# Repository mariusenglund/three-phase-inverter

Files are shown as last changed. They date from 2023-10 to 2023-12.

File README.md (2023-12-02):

# 3-phase DC/AC converter with SV-PWM
This repository holds materials of our bachelor's thesis carried out at the Western Norway University of Applied Sciences (HVL), Department of Computer Science, Electrical Engineering and Mathematical Sciences in the spring of 2023.

The thesis can be found at [HVL Open](https://hdl.handle.net/11250/3105460).

> We hope that this report will serve as a valuable resource for those who are interested in the field, and we encourage further development of the provided resources.

## About the Project
The project was aimed at realizing the design and fabrication of a three-phase DC-to-AC converter utilizing the Space Vector Pulse Width Modulation (SV-PWM) algorithm.

<p align="center">
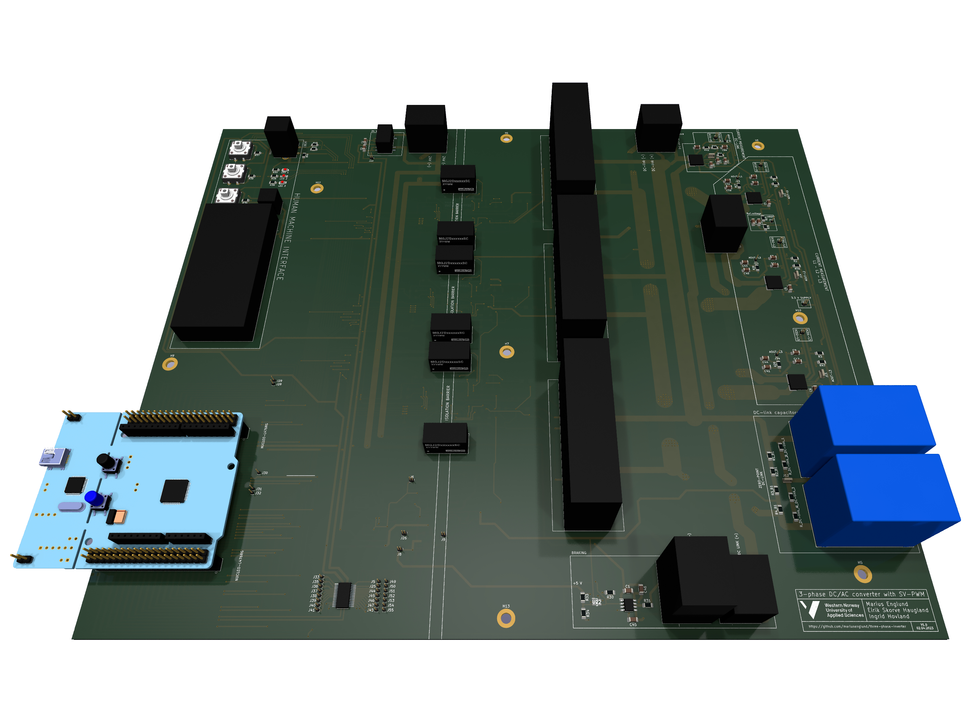
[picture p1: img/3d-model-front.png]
3D Model Front
   
   &nbsp; &nbsp; &nbsp; &nbsp;
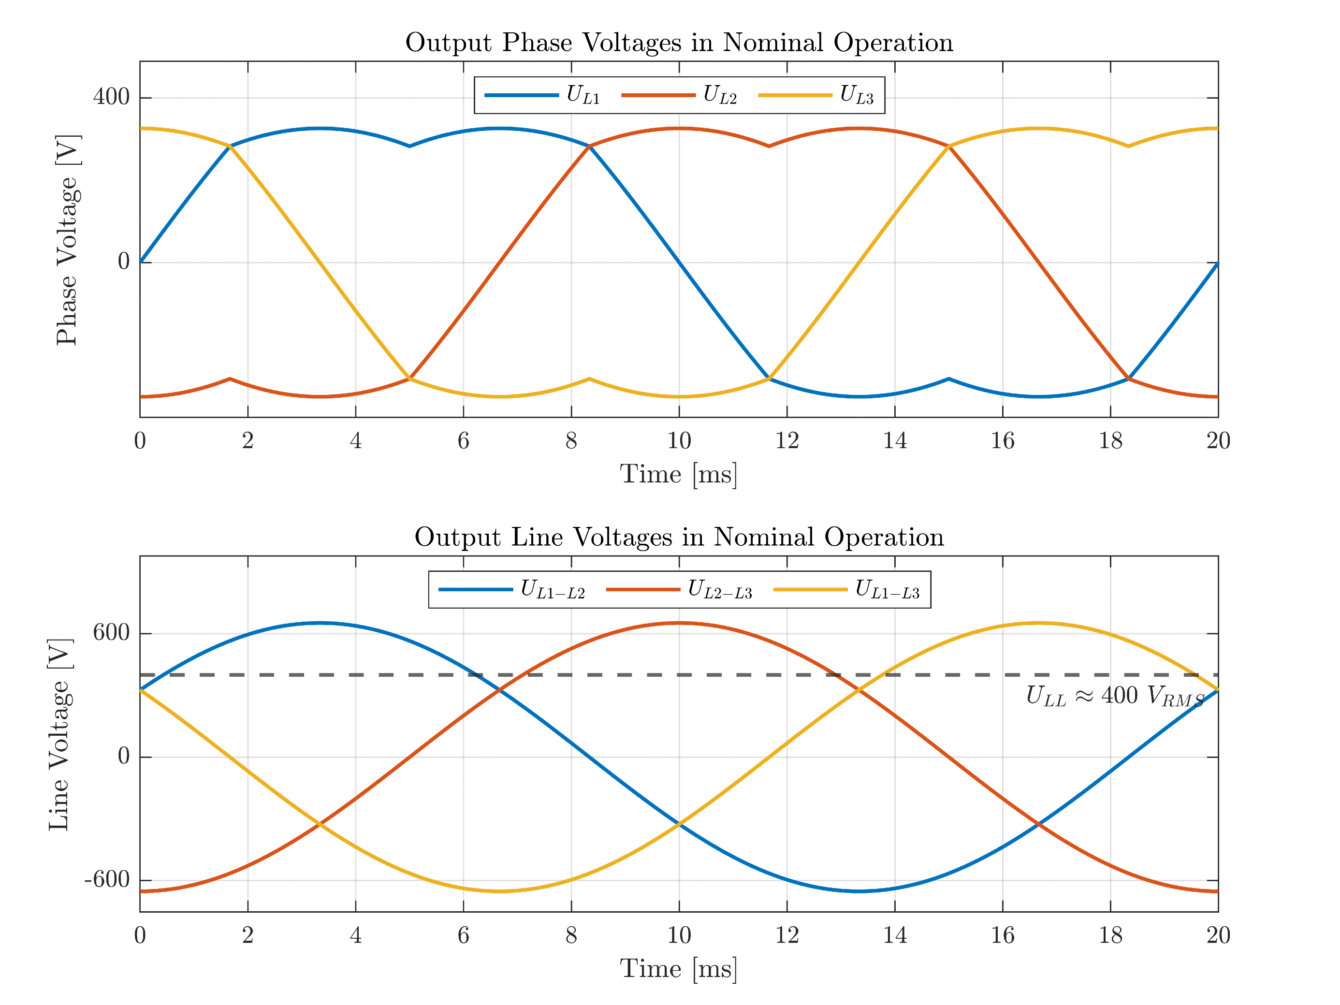
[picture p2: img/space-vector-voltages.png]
Space Vector Voltages
   
</p>

## Further Work
For suggestions on further work, please refer to the thesis.

## Available Resources
In order to facilitate further advancement, the following resources are made accessible from this repo:

* [PCB design files](pcb-design-files)
* [Source code](source-code)
* [Simulation files](simulation-files)

The repository also contains a [laboratory exercise proposal](/laboratory-exercise/laboratory-exercise-proposal.pdf) that makes use of the inverter. It is worth noting that this exercise is presented in Norwegian.

## License
The resources provided in this repository are released under the GNU General Public License. See the [LICENSE](LICENSE) file for more information.

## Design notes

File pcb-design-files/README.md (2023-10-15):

## PCB Design Files
Download the KiCad project from this location.

***Be aware that the files are still a work in progress.***

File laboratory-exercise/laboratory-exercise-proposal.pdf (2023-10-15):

# Lab - 2-nivå trefase DC/AC-omformar¹

## Emnekode: ELE119

## Emnenamn: Kraftelektronikk

## Haust 2023

Labansvarleg: Lars M. Ekroll lme@hvl.no

Emneansvarlig: Eirik Haustveit
| ehau@hvl.no

Utlevert:
dd.mm.åååå

Frist:
dd.mm.åååå
Gjennomføring:
dd.mm.åååå

Denne laboratorieoppgåva dekker grunnleggande praktisk bruk av ein 2-nivå trefase DC/AC-omformar.

Spenningane og straumane som skal nyttast i oppgåva er moderate, men framleis på eit nivå som medfører

fare. Før arbeidet kan starta er det derfor obligatorisk med ein sikkerhetsgjennomgang for alle studentar

som skal gjennomføra oppgåva.

Figur 1: 150 V, livsfare.

- 2-nivå trefase-omformar
- Romvektormodulering - SV-PWM
- Sinuspulsbreiddemodulering - SPWM

1 Denne laboratorieoppgåva er utvikla av Marius Englund, Eirik Skorve Haugland og Ingrid Hovland, med utgangspunkt i ein mal utarbeidd av Eirik Haustveit.

Lab 1 | ELE119 - Kraftelektronikk | Haust 2023

## 1 Introduksjon

Denne laboratorieoppgåva dekker 2-nivå trefase-omformar. Oppgåva er strukturert i 3 delar:

1. Forarbeid: Her skal ein berekne nokre aktuelle parameter. I tillegg skal ein simulera berekna verdiar. Resultata frå berekningar og simuleringar skal noterast i oversiktstabellen.
2. Laboratoriearbeid: Her skal ein utføre oppkoplinga, samt måling på dei fysiske modellane. Det vil være ein stor fordel om ein har gjort seg godt kjent med ein simuleringsmodell og verktøya i forkant. Grunnleggande forståing for dei to modulasjonsteknikkane SPWM og SV-PWM er og ein stor fordel. Ein skal samle måleresultat i all hovudsak ved hjelp av oscilloskop. På oscillioskopet har ein verktøy som er kjent frå Simulink, som å måla verdiar som RMS, snitt, peak-peak, FFT m.m. Ein skal også lagre datasett som CSV-filer for å kunne etterbehandla dei i Matlab. Her er det viktig at ein organiserer arbeidet, slik at ein har kontroll på kva målingar som ligg i eit gitt datasett.
3. Etterarbeid: I etterarbeidet skal ein samanlikne utrekna, simulerte og fysiske måleresultat og studere avvika som ev. viser seg. Ein skal og tolke datasett frå laboratoriearbeidet.

Arbeidet skal oppsummerast i ein enkel rapport som dokumenter dei ulike delane av oppgåva.

### 1.1 Føresetnader

Arbeidet blir utført på spenningssatt anlegg med maksimal spenning 230 V. Då dette er eit spenningsnivå som har skadepotensial for både personar og utstyr, er ein tryggleiksgjennomgang med ansvarleg for elkraft-laboratoriet, Lars M. Ekrol påkrevd før den praktiske delen av oppgåva kan gjennomførast.

### 1.2 Utstyr

Under fylgjer ei liste over utstyr som blir gjort tilgjengeleg for den praktiske gjennomføringa. Noter utstyrsnummeret du har brukt i tabell 1. Om det er avvik frå ditt oppsett skal dette avviket noterast i din rapport.

Tabell 1: Liste over utstyr til lab

Utstyr | Skildring | Utstyrsnr | Kommentar
Trafo | 2 kVA trafo, 220/133 V
Brytar | Brytar i tilførsel
Brytar | Brytar i last
Sikring | 3 fase, 2/6 A
Koblingsboks | For tilkopling og måling
Kraftmodul | 2-nivå trefase-omformar
Spenningsprobe 1 | Micsig DP1003
Spenningsprobe 2 | Micsig DP1003
Strømtang 1 | Micsig CP2100A
Strømtang 2 | Micsig CP2100A
Multimeter | Hioki DT4282
| Koplingsleidningar med bananplugg
Effektmotstand | Belastningsmotstand
Effektmotstand | Straumbegrensingsmotstand for kondensator

Side 1 av 8

Lab 1 | ELE119 - Kraftelektronikk | Haust 2023

### 1.3 Måleinstrument

For å gjennomføra denne laboratorieoppgåva er det nødvendig å ha kjennskap til dei måleinstrumenta ein skal nytta. I all hovudsak skal oscilloskop nyttast til målingane, men det kan og vera aktuelt å foreta enkelte målingar med multimeter. Figur figur 2 viser oscilloskopet som skal nyttast. Det føresett grunnleggande forkunnskap i å bruka oscilloskopet, som justering av skallering, tid, størrelse, trigger og liknande. Vedlegg A gir ei enkel innføring i korleis ein stillar in probar, samt korleis ein hentar ut relevante målingar.

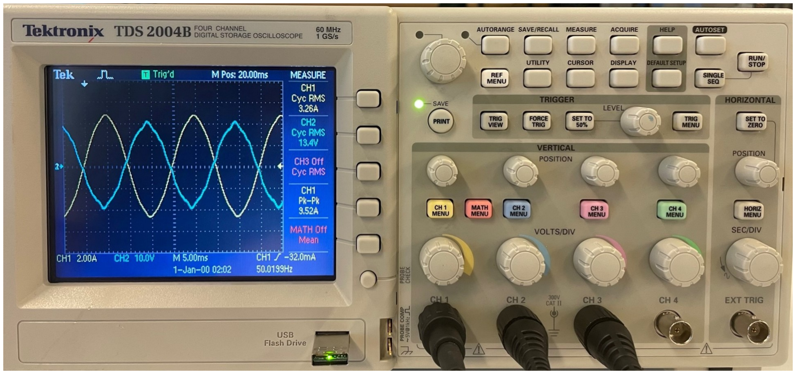
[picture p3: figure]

Figur 2Bilde av oscilloskop, Tektronix TDS 2004B

Side 2 av 8

Lab 1 | ELE119 - Kraftelektronikk | Haust 2023

## 2 2-nivå trefase-omformar

Oppgåve 1
I denne oppgåva skal de gjera målingar på ein 2-nivå trefase-omformar. Omformaren består av ein DC-link og seks transistorar som kan verta styrt med forskjellige modulasjonsteknikkar. I denne oppgåva skal dei to modulasjonsteknikkane sinuspulsbreiddemodulasjon (SPWM) og romvektormodulasjon (SV-PWM) samanliknast.

Tilført spenning Us = 150 V med frekvensen f1 = 50 Hz.

Forarbeid:
(a) Utfør berekning av verdiar gitt i tabell 2 for SPWM og SV-PWM.
(b) Simuler verdiane gitt i tabell 2.

Laboratoriearbeid:
Dei akutelle “measure” verdiane frå skopet skal noterast i tabell 2.
(a) Kontroller at du har tilgong på nødvendig utstyr, og kople opp omformaren mot last. Alle
| målingane skal gjerast for både SPWM og SV-PWM.
(b) Skru på DC-link spenning og svitsjing i mikrokontroller ved å trykke start på kortet. Observer tilført og avgitt spenning på oscilloskopet. Du skal bruka “measure” funksjonen i skopet til å finna frekvens, snitt, peak-peak og RMS verdi av målingane. Vidare skal du lagra eit datasett av målingane til ein minnepinne. For referanse skal PWM frå mikrokontroller vera med på alle målingar frå skopet.
i. Foreta ei samtidig måling av tilført, samt avgitt spenning. Noter “measure” verdiane.
| ii. Foreta ei måling av tilført, samt avgitt straum. Noter “measure” verdiane.
iii. Foreta ei samtidig måling av tilført straum og spenning. Bruk “math” funksjonen i skopet til å finna effektkurva og ta snittet av denne kurva for å finna aktiv effekt. Noter “measure” verdiane.
iv. Foreta ei samtidig måling av avgitt straum og spenning. Bruk “math” funksjonen i skopet til å finna avgitt aktiv effekt. Noter “measure” verdien av snittet til den berekna effektkurva.
v. Mål det harmoniske innhaldet i spenning.

Etterarbeid:
(a) Vurder kva som er årsaka, dersom det er nokon ruter i tabellen som står tomme. Kvifor er dette verdiar som er vanskelig å berekna, eller å måla fysisk? Dersom du har fyllt ut heile tabellen,
| treng du ikkje svare på denne oppgåva.
(b) Vurder årsaker til avvik mellom berekningar og fysiske målingar. Ta omsyn til toleransar i
| måleinstrument, og ikkje-ideelle eigenskapar ved diodane.
(c) Samalikn kurvene frå datasetta til SPWM og SV-PWM. Kva er årsaken til likheitar og ulikheitar?
(d) Samanlikn målte og simulerte resultat av dei to modulasjonsteknikkane.

Side 3 av 8

Lab 1 | ELE119 - Kraftelektronikk | Haust 2023

Tabell 2. Samanlikning mellom berekna, simulerte, og målte verdiar

| | | SPWM | | | SV-PWM
Storleik | Skildring | Kalk. | Sim. | Målt | Kalk. | Sim. | Målt
U¯
d | Avgitt snittspenning
Ud | Avgitt RMS spenning
¯Id | Avgitt snittstraum
∆Ud | Rippel i avgitt spenning
Us | Tilført RMS spenning | 150 V | 150 V | | 150 V | 150 V
Is | Tilført RMS straum
Is1 | Grunnharmonisk RMS straum
Is3 | RMS av 3 harmoniske i tilført straum
THDi | THD i tilført straum
Pd | Avgitt aktiv effekt | X | | | X
Ps | Aktiv effekt frå Us | X | | | X
PF | Total effektfaktor | X | | | X

Side 4 av 8

## A Innstilling og bruk av oscilloskop

Dette vedlegget gir ei kort inføring i det oscilloskopet, samt dei måleprobane ein skal nytta i denne laboppgåva.

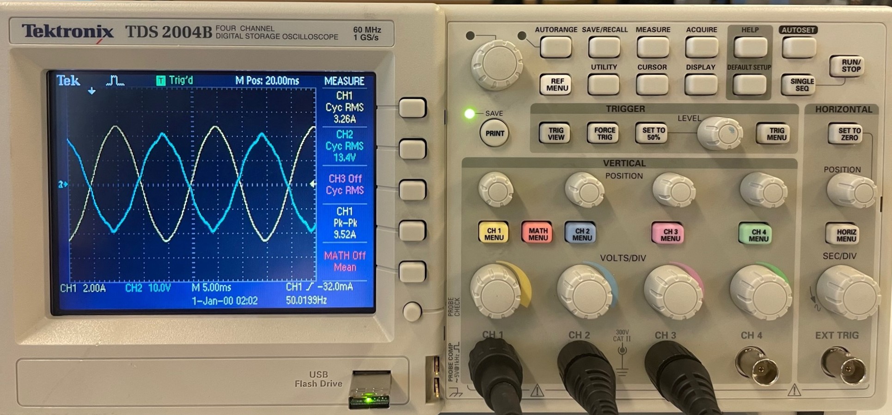
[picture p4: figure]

Figur 3Bilde av oscilloskop, Tektronix TDS 2004B

A.1 Differensialprobe for spenningsmåling

Differensialproben Micsig DP10013 skal brukast til spenningsmåling og kan operera opptil 1,3 kV. Proben kan stillast på 2 måleområder, X50/X500, og ein må velga det området som passar best for dei spenningane ein forventer å måla. For riktig avlesing på oscilloskopet må ein stilla det inn på det samme måleområdet som proben.

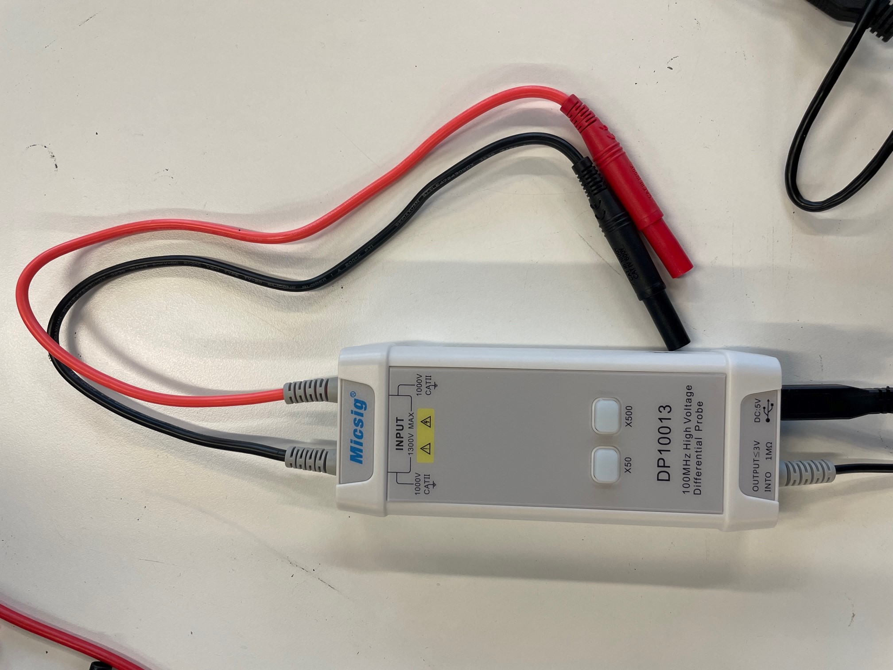
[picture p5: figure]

Figur 4Bilde av differensialprobe for spenningsmåling, Micsig DP1003

Frå kanal menyen “CH X MENU” får ein individuelle valg per kanal i sidemenyen. “Coupling”, skal vera DC. For spenningsproben velger ein “Voltage” og “Attenuation” 50X eller 500X avhengig av din probeinnstilling.

A.2 Tangamperemeter for straummåling

Straumtanga Micsig CP2100A skal brukast til straummåling og kan operere opptil 100 A. Proben kan stillast på 2 måleområder, 10 eller 100 A.
Frå kanal menyen “CH X MENU” får ein individuelle valg per kanal i sidemenyen. “Coupling”, skal vera DC. For straumtanga velger ein “Current” og “Scale” etter minste måleområde, 100 mV/A. Sjekk at straumtanga lyser på 10 A måleområde. Når skalering er utført kan ein nullstille straumtanga ved å trykke “Zero” og evt. justere DC-offset med pilene dersom den ikkje viser 0 A før du begynner å ta målingar.

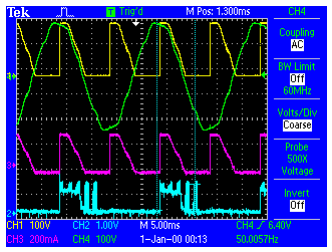
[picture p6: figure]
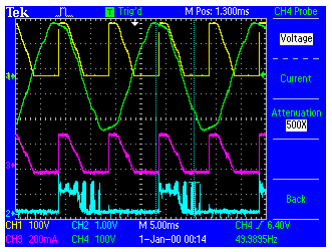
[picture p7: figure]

(a) Sidemeny etter valg av “CH X MENU”. | (b) Sidemeny etter valg av “Probe”

Figur 5Instilling av spenningsprobe

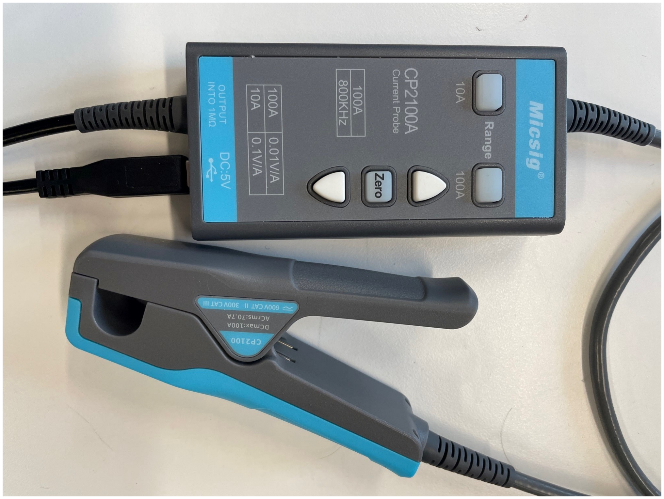
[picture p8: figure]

Figur 6Bilde av strømtang, Micsig CP2100A

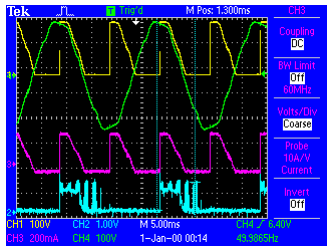
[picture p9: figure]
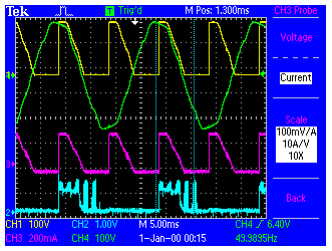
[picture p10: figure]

(a) Sidemeny etter valg av “CH X MENU” | (b) Sidemeny etter valg av “Probe”

Figur 7Instilling av straumtang

A.3 Målingar på skop

Oscilloskopet har ein “measure”-funksjon som kan gi oss forskjellige verdiar ut frå dei kurvene me måler. Denne funksjonen skal me nytta til å henta ut RMS, snitt, peak-peak og frekvens. For å definere målingar mot gitt kanal trykker ein på “measure” og velger målepunkt i sidemenyen. Frå sidemenyen velger ein spesifikk kanal og kan vidare definere kjelde, og målefunksjon.

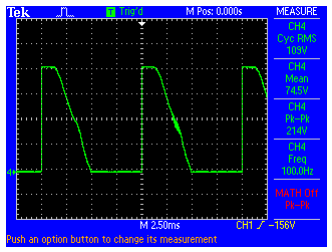
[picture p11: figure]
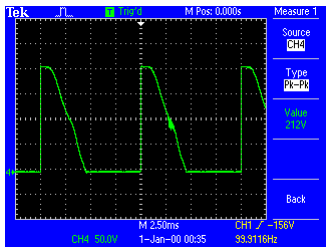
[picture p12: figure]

(a) Sidemeny etter valg av “Measure” | (b) Sidemeny etter valg av spesifik måling

Figur 8Instilling av målingar som RMS, snitt, peak-peak, frekvens med fleire

A.4 Bruk av “cursors” på skop

“Cursors” kan nyttast for å sjå dei forskjellige kurvene i relasjon til kvar andre, eller for å finna relasjonen mellom forskjellige punkt på den samme kurva. Ein kan avlesa distanse i tid, eller i spenning eller straum. For å aktivera trykker ein på “Cursors” og velger type og kanal. Ein velger mellom dei 2 målelinjene, “Cursors”, i sidemenyen og kan flytte disse individuelt med multi-purpose hjulet. Punktavlesning per målelinje kan lesast av samt differansen mellom dei 2 målelinjene.

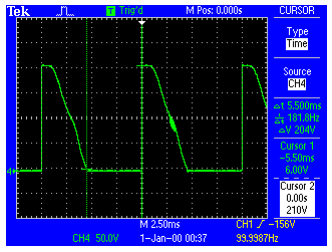
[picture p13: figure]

(a) Vertikale “Cursors” for punktavlesning og tidsdifferanse

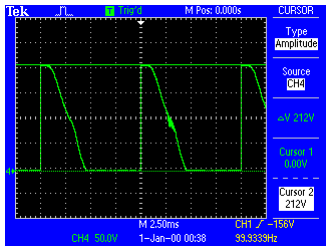
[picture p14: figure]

(b) Horistontale “Cursors” for punktavlesning og amplitudedifferanse

Figur 9Bruk av “Cursors” til måling av signal

A.5 Matte-funksjonar

Ein kan bruke scopet til å rekne ut samanhengar mellom kanalar samt gjera nokre analysar per kanal. For å berekne effekt kan ein multiplisere straum og spenning ved å trykker på “MATH MENU” ved å velge X i operasjon fra sidemenyen. Matte-funksjonen kan vidare hentast inn i “Measure” bildet
Ein kan og gjere måling av harmonisk spekter for ein kanal ved å trykker på “MATH MENU” ved å velge kilde referert til kanal, source, samt FFT frå sidemenyen. Ein kan i dette bildet bruke “Cursors” til å lese av frekvens/amplitude.
Figur 11 viser eit døme på FFT-bilde frå skopet.
FFT målingane på Tektronix TDS 2004B er oppgitt i desibel relativt til ei RMS spenning på 1 V. Den fylgjande formelen syner samanhengen mellom spenning og desibel:

dBV = 20 log
U

1 V
(1)

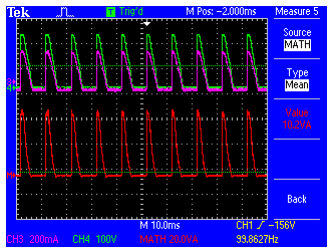
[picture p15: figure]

(a) Sidemeny og effektkurve etter valg av “Measure” mot mattefunksjon

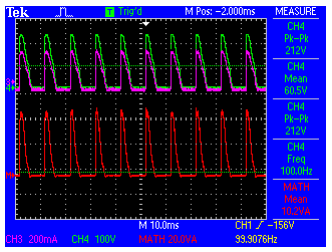
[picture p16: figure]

(b) Sidemeny inkludert målingar og mattefunksjon

Figur 10Bruk av mattefunksjon til å multiplisere straum og spenning

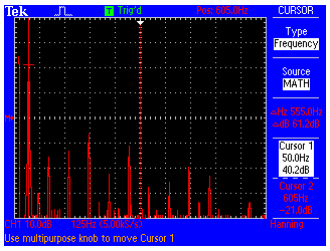
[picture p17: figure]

Figur 11FFT-måling

A.6 Total harmonisk forvrenging

Det er ikkje vanleg at oscilloskopet har innebygd støtte for berekning av total harmonisk forvrenging. Det er derimot mulig å berekna verdien frå dei harmoniske komponentane ein finn i spektrumsanalysatoren.

THDu =

p
U

2
2 + U

2
3 + U

2
4 + . . .
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
+ . . . | (2)

Differansen mellom den grunnharmoniske og ein overharmonisk komponent kan uttrykkast som:

dBc = 10 · log
P
Pc
(3)

Der P er den overharmoniske og Pc er den grunnharmoniske (carrier). Denne verdien kan normalt finnast ved å plassera ein "cursorpå den grunnharmoniske, og ein anna "cursorpå den overharmoniske komponenten som er av interesse. Verdien ein er ute etter er ofte uttrykt som ∆dB.

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
= 10

dBc
10

(5)

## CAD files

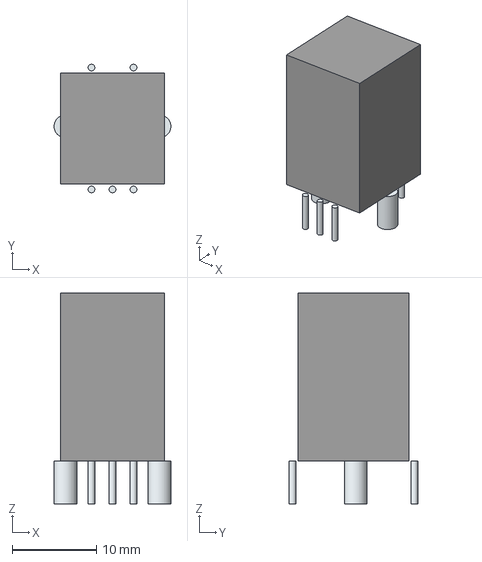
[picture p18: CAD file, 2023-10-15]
pcb-design-files/LIB-3D/Encoder_EC12E2424407.stp
13.9 x 15.3 x 25.1 mm
Leads

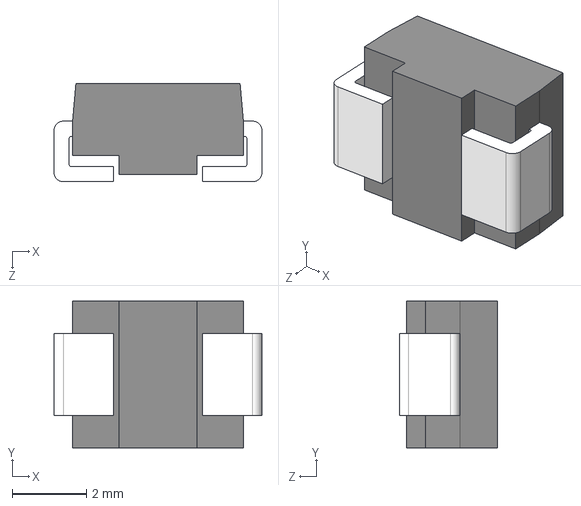
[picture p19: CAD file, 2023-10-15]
pcb-design-files/LIB-3D/Diode-STTH112U.stp
5.60 x 3.95 x 2.65 mm

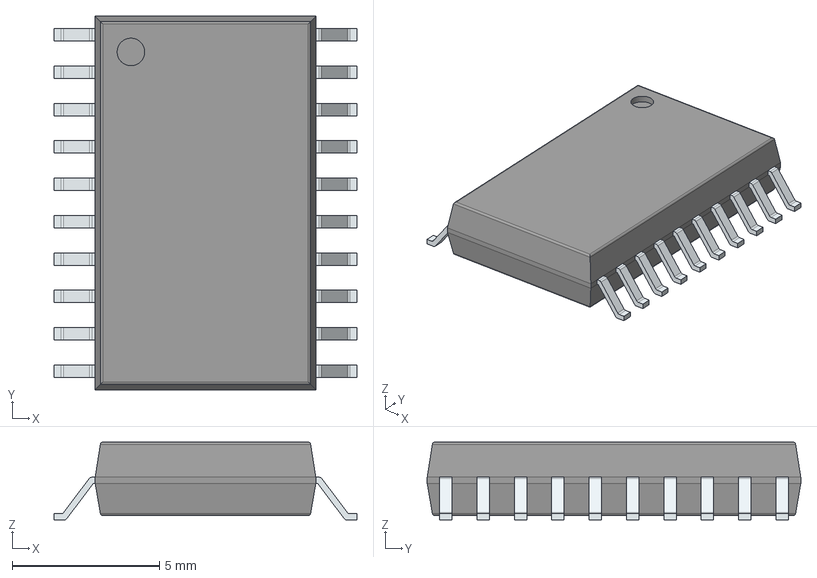
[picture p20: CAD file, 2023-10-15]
pcb-design-files/LIB-3D/1ED020I12FA2XUMA2.stp
10.3 x 12.7 x 2.65 mm
PinsArrayLR

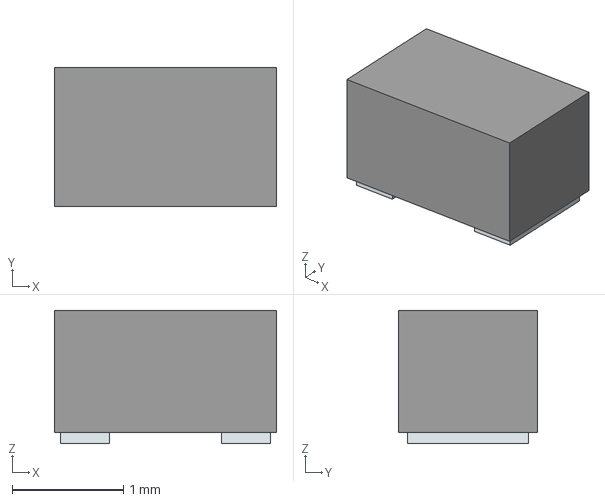
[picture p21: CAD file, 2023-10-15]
pcb-design-files/LIB-3D/LED_yellow_SML-LX0805SYC-TR.stp
2.00 x 1.25 x 1.20 mm
Pins

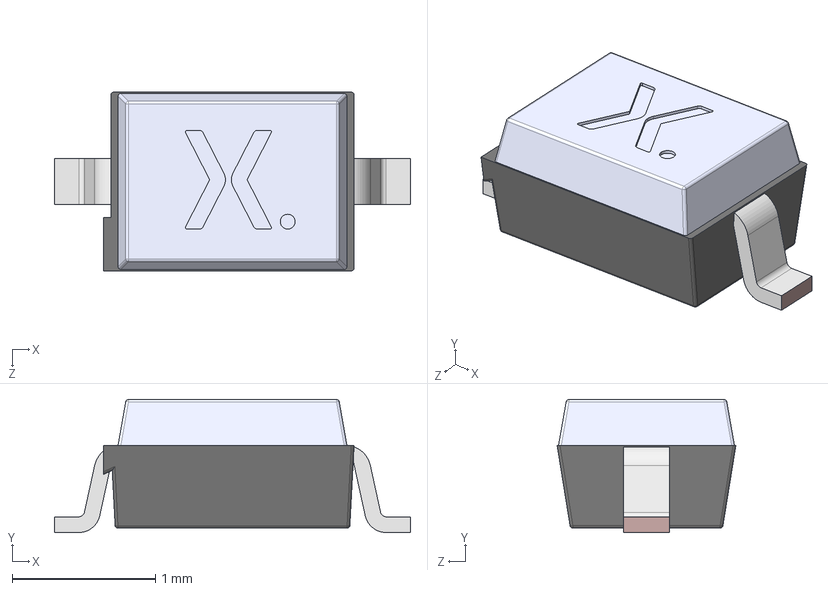
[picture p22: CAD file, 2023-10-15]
pcb-design-files/LIB-3D/Schottky-BAT165AX.stp
2.49 x 0.93 x 1.25 mm
SOD323 Lower body
SOD323 Lead x 2
SOD323 Upper body

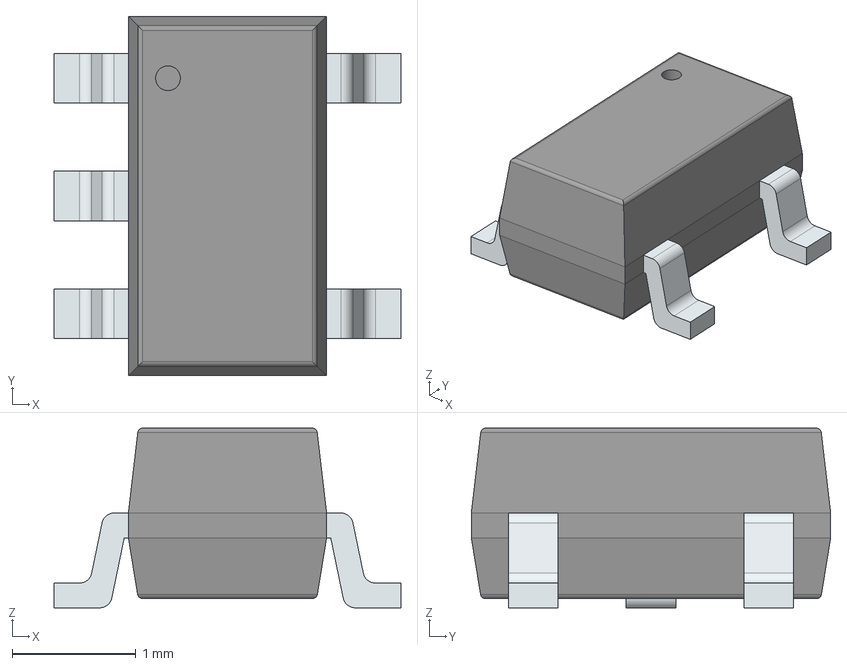
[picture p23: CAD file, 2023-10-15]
pcb-design-files/LIB-3D/OPA237NA_250.stp
2.80 x 2.90 x 1.45 mm
PinsArrayL
PinsArrayR

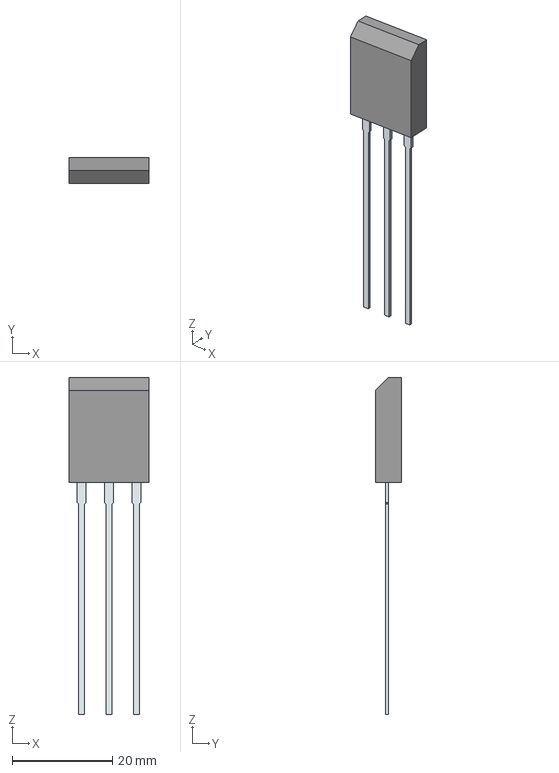
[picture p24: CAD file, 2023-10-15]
pcb-design-files/LIB-3D/IKW40N120H3.stp
15.9 x 5.21 x 67.1 mm
PinsArray

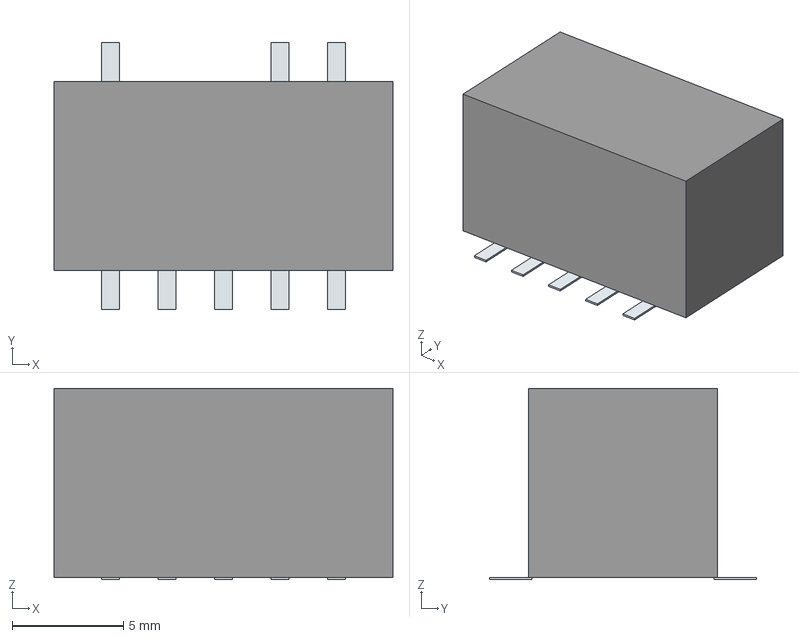
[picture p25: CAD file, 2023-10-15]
pcb-design-files/LIB-3D/MP-K7803T-500R3.stp
15.2 x 12.0 x 8.60 mm
Pins

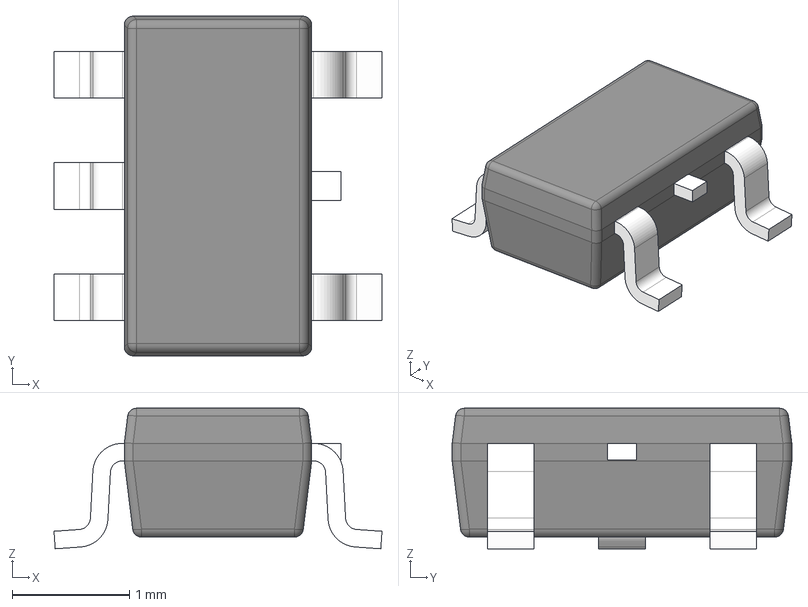
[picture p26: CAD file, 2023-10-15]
pcb-design-files/LIB-3D/LMV331M5.stp
2.80 x 2.90 x 1.20 mm
BODY-SOT
LEAD-SOT x 5
LEAD-DUMMY

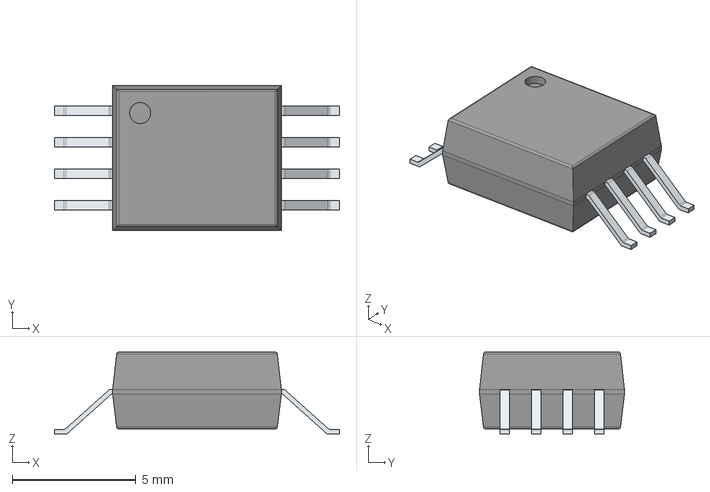
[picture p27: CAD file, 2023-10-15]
pcb-design-files/LIB-3D/ACPL-C87B-000E.stp
11.5 x 5.85 x 3.31 mm
PinsArrayLR

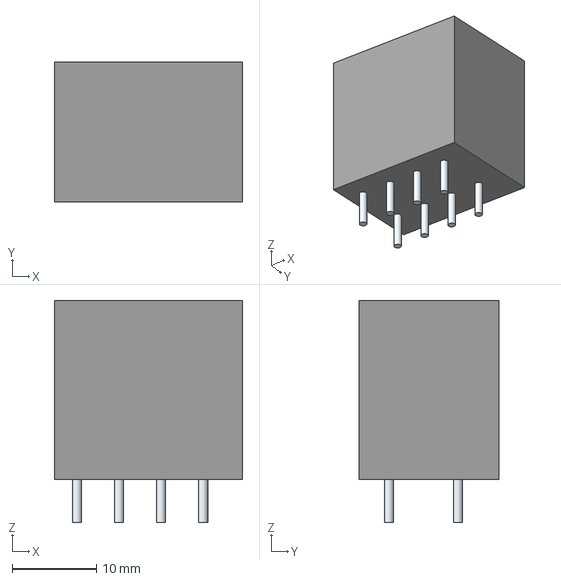
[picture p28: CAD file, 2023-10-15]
pcb-design-files/LIB-3D/WAGO-2604-3104.stp
22.4 x 16.7 x 26.4 mm
Leads

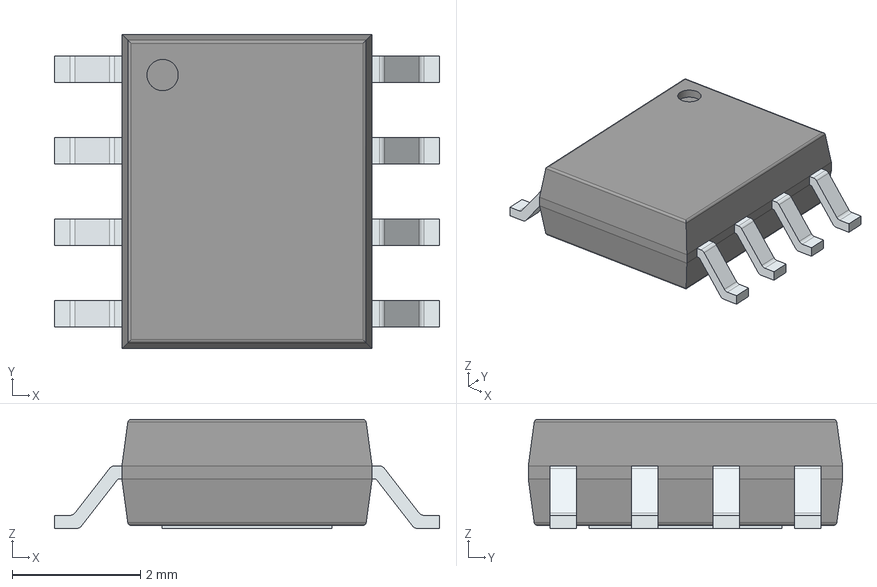
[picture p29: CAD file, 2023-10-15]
pcb-design-files/LIB-3D/TLS205B0EJV33XUMA1.stp
6.00 x 4.90 x 1.70 mm
PinsArrayLR
ThermalPad

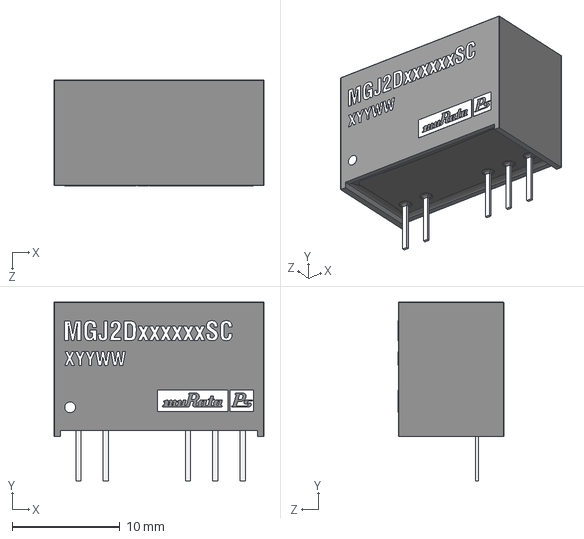
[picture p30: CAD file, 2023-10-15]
pcb-design-files/LIB-3D/MGJ2D241509SC.stp
19.5 x 16.6 x 9.82 mm

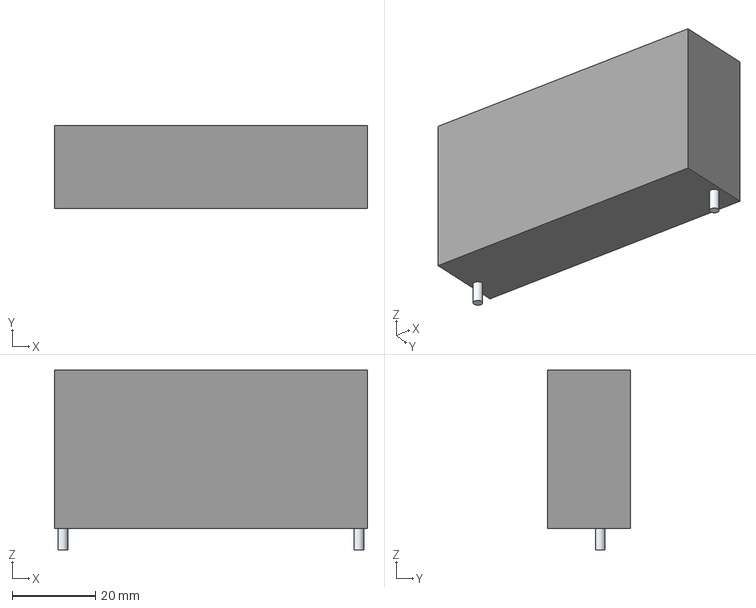
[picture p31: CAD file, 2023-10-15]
pcb-design-files/LIB-3D/Heatsink_C247-075-3AE.stp
75.0 x 19.9 x 43.1 mm
Leads x 2

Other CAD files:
pcb-design-files/LIB-3D/74LV1T34GV-Q100H.stp
pcb-design-files/LIB-3D/DC-link-capacitor-B32776G0146K000.stp
pcb-design-files/LIB-3D/Keystone - 5019 - PCB Test Point v1.step
pcb-design-files/LIB-3D/61304021821.stp
pcb-design-files/LIB-3D/B3F-5050.stp
pcb-design-files/LIB-3D/C247-025-1VE.stp
pcb-design-files/LIB-3D/Display_MC21605C6W-SPTLYI-V2.stp
pcb-design-files/LIB-3D/IR2118SPBF.stp
pcb-design-files/LIB-3D/LED_red_SML-LX0805SIC-TR.stp
pcb-design-files/LIB-3D/MCP23017T-E_SS.stp
pcb-design-files/LIB-3D/NTE0505MC.stp
pcb-design-files/LIB-3D/TLI4971A050T5UE0001XUMA1.stp
pcb-design-files/LIB-3D/UCC27321DR.stp

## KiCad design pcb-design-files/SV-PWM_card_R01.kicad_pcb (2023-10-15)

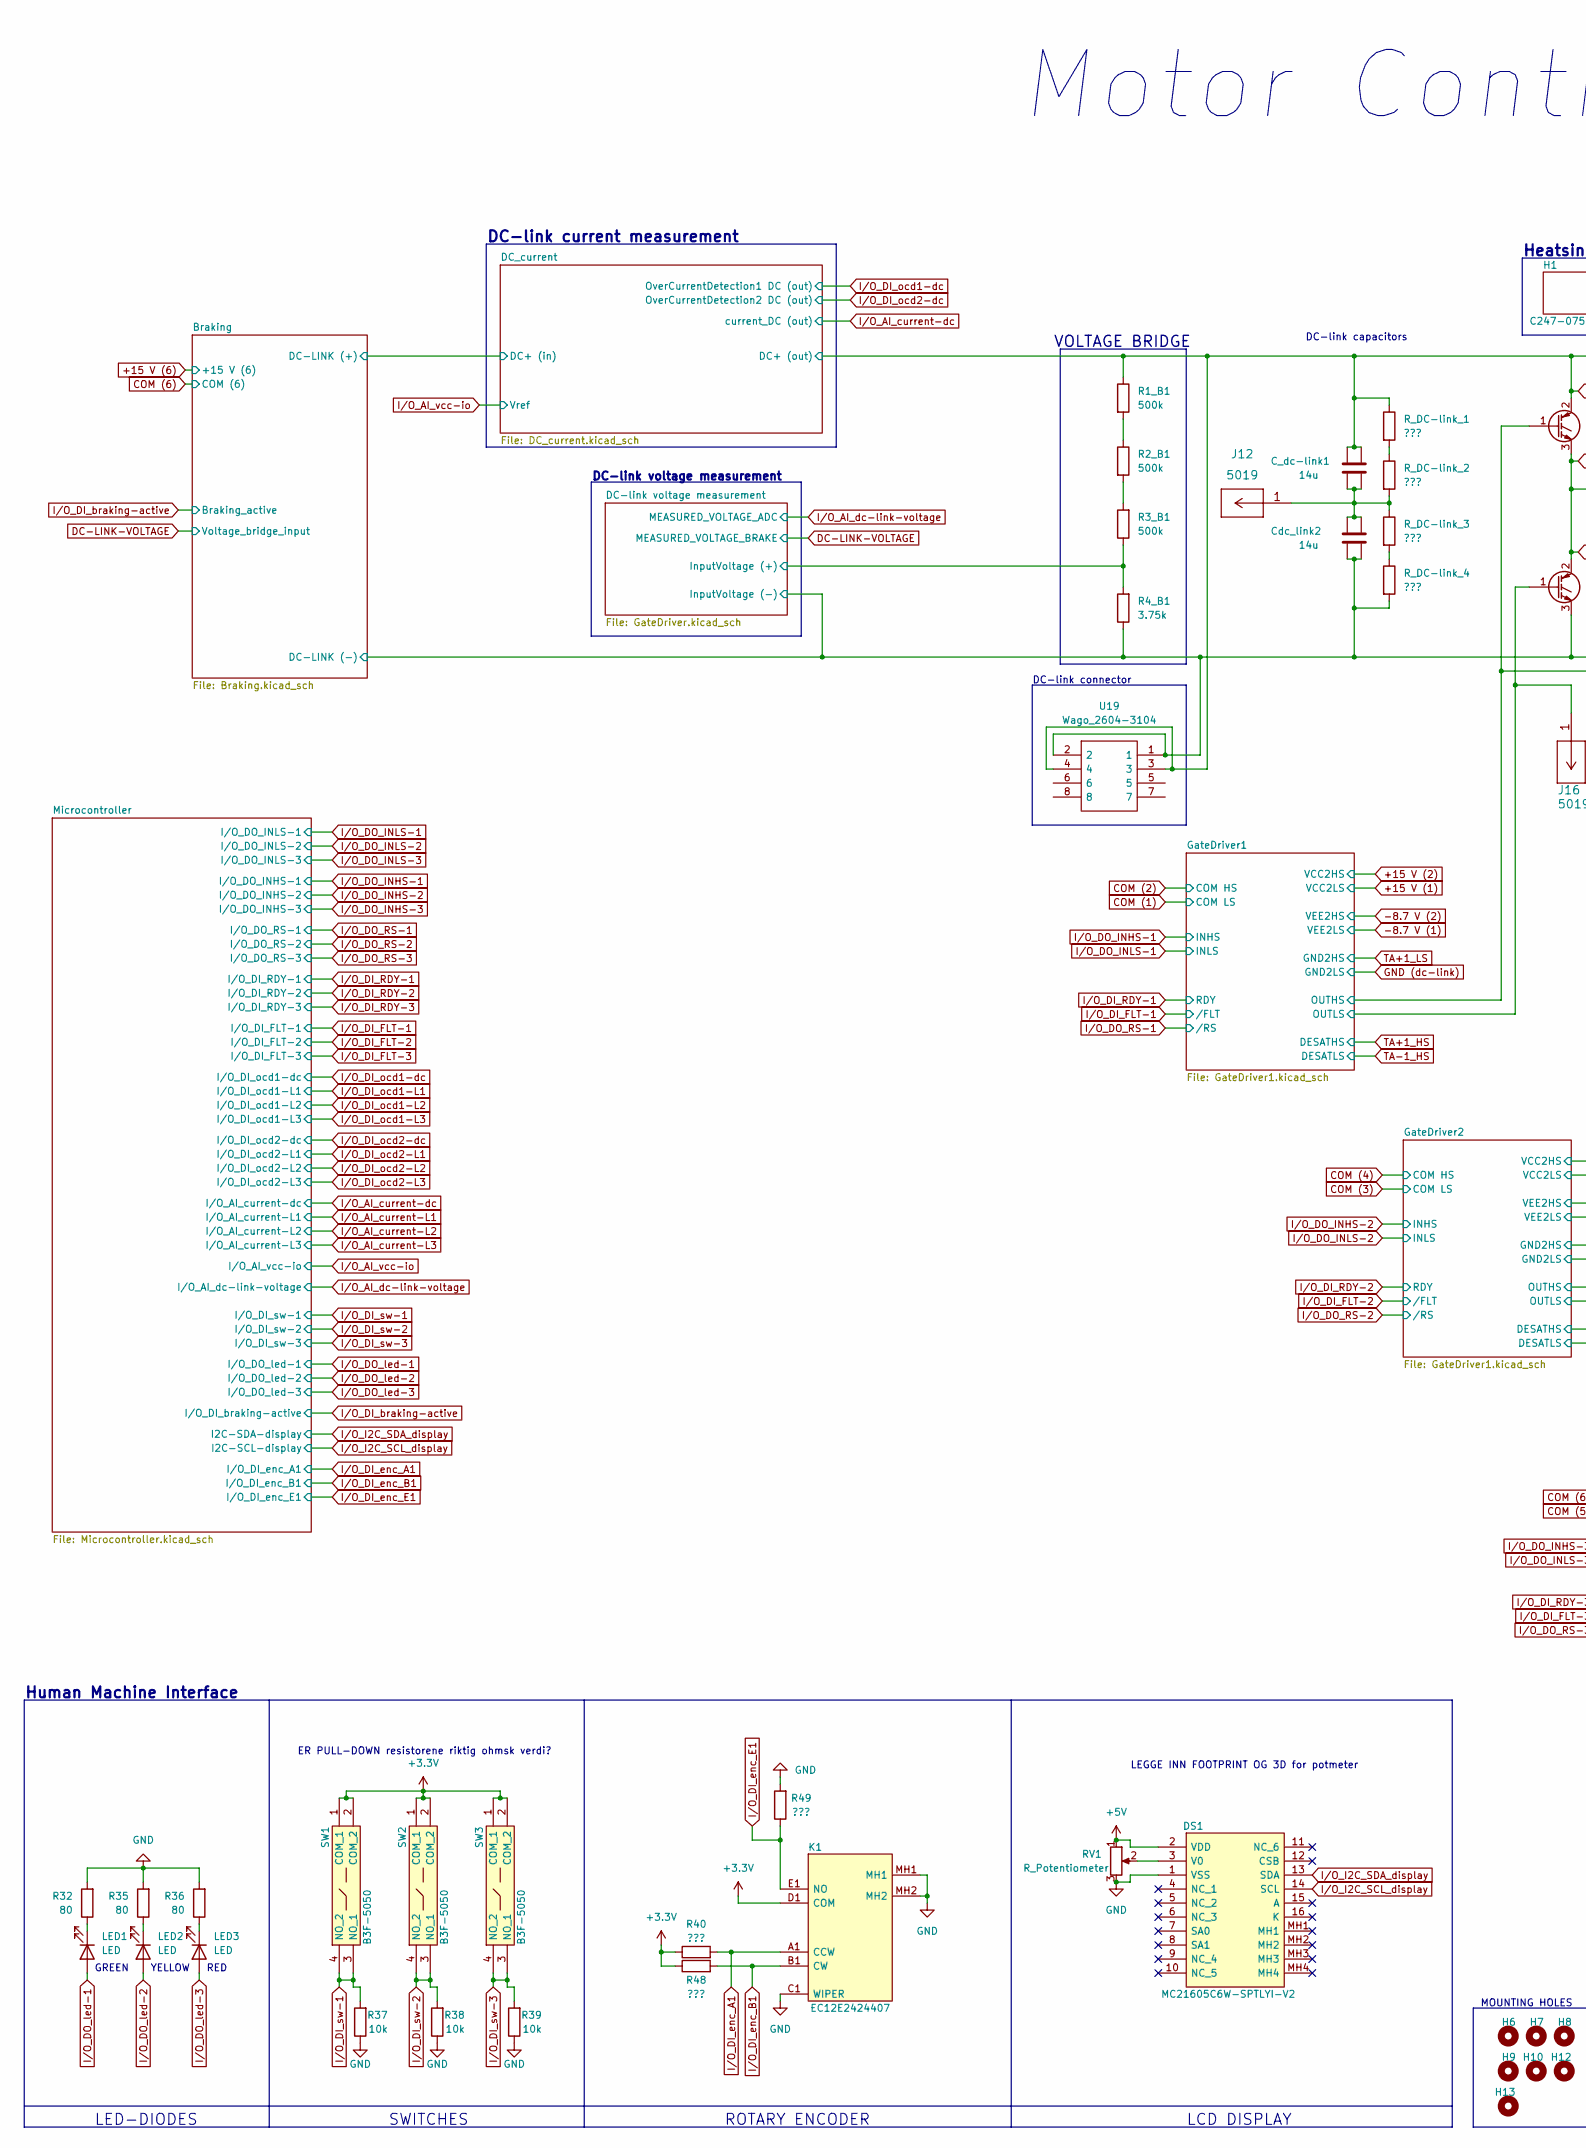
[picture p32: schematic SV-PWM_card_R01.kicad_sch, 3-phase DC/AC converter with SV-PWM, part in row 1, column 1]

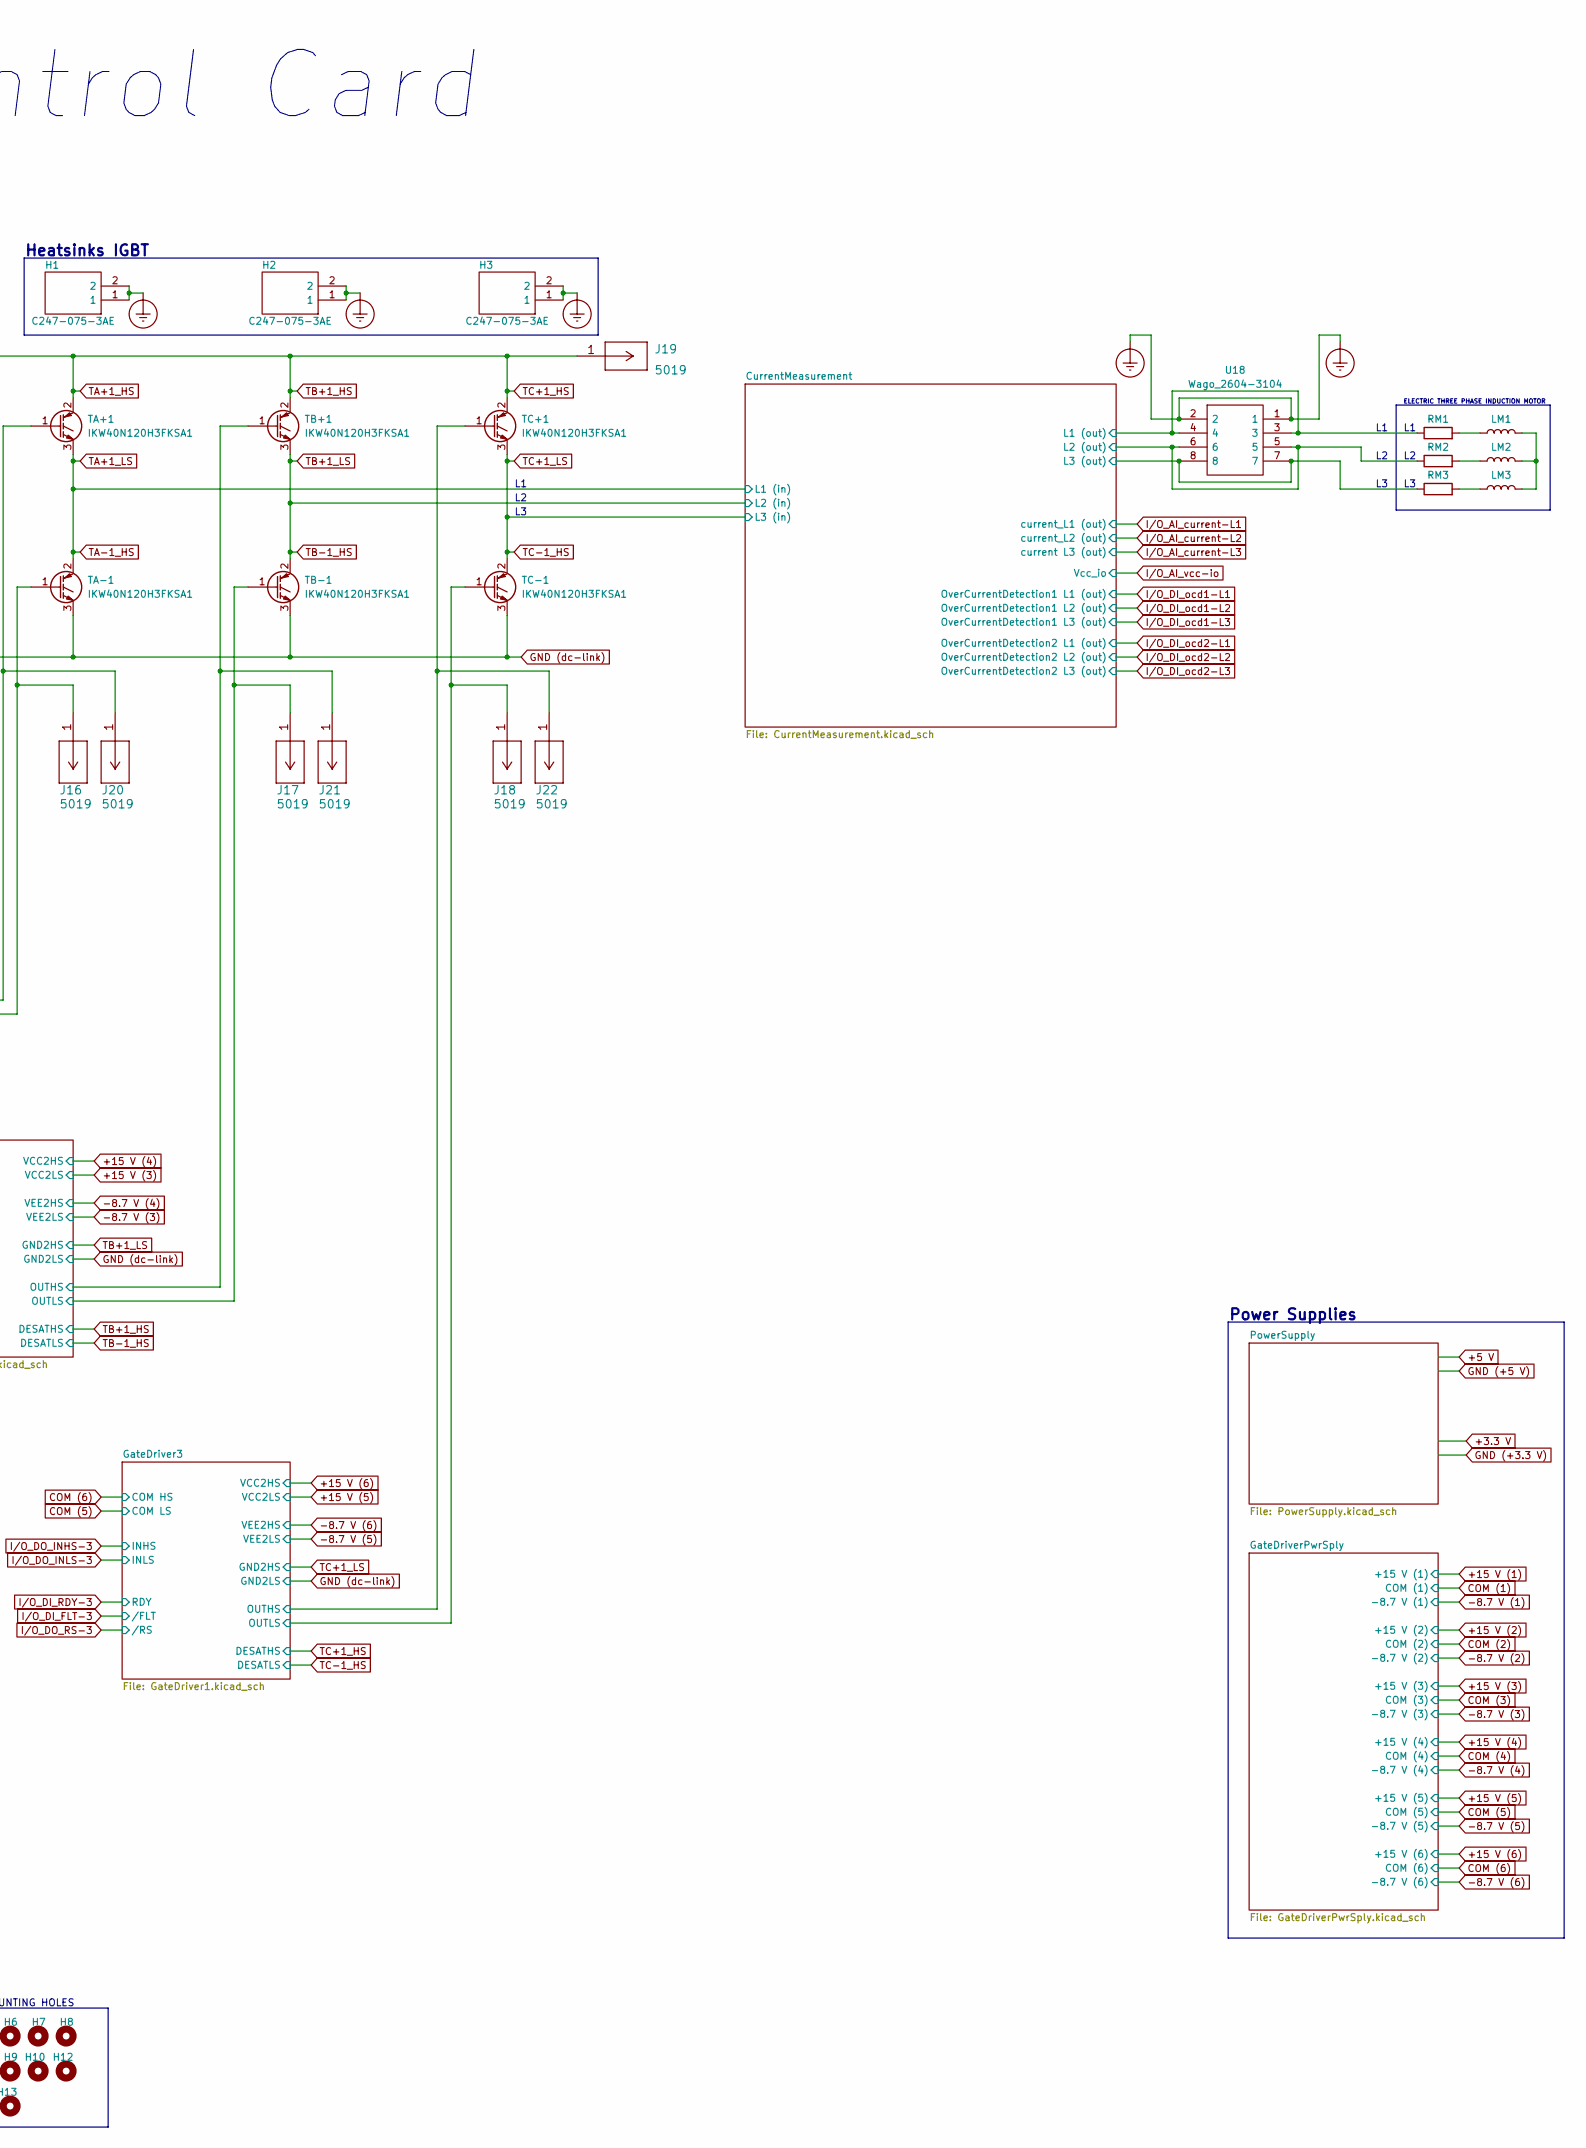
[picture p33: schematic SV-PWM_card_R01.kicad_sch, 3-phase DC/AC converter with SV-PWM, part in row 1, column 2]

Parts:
C_dc-link1: 14u; DC-link-capacitor-B32776G0146K000
Cdc_link2: 14u; DC-link-capacitor-B32776G0146K000
DS1: MC21605C6W-SPTLYI-V2; Display_MC21605C6WSPTLYIV2; Manufacturer_Part_Number MC21605C6W-SPTLYI-V2
H1, H2, H3: C247-075-3AE; Heatsink_C2470753AE; Manufacturer_Part_Number C247-075-3AE; Mouser Part Number 588-C247-075-3AE
H6, H7, H8, H9, H10, H12, H13: MountingHole; MountingHole_4.3mm_M4_DIN965_Pad
J12, J16, J17, J18, J19, J20, J21, J22: 5019; Keystone-5019
K1: EC12E2424407; Encoder_EC12E2424407; Manufacturer_Part_Number EC12E2424407; Mouser Part Number 688-EC12E2424407
LED1: LED; LED_green
LED2: LED; LED_yellow
LED3: LED; LED_red
LM1, LM2, LM3: L
R1_B1, R2_B1, R3_B1: 500k; R_1206_3216Metric_Pad1.30x1.75mm_HandSolder
R4_B1: 3.75k; R_1206_3216Metric_Pad1.30x1.75mm_HandSolder
R32, R35, R36: 80; R_1206_3216Metric_Pad1.30x1.75mm_HandSolder
R37, R38, R39: 10k; R_1206_3216Metric_Pad1.30x1.75mm_HandSolder
R40, R48, R49: ???; R_1206_3216Metric_Pad1.30x1.75mm_HandSolder
RM1, RM2, RM3: R
RV1: R_Potentiometer; Potmeter_3386F1203TLF
R_DC-link_1, R_DC-link_2, R_DC-link_3, R_DC-link_4: ???; R_1206_3216Metric_Pad1.30x1.75mm_HandSolder
SW1, SW2, SW3: B3F-5050; B3F-4055; Manufacturer_Part_Number B3F-5050; Mouser Part Number 653-B3F-5050
TA+1: IKW40N120H3FKSA1; IGBT-TO544P521X1592X2557-3P
TA-1: IKW40N120H3FKSA1; IGBT-TO544P521X1592X2557-3P
TB+1: IKW40N120H3FKSA1; IGBT-TO544P521X1592X2557-3P
TB-1: IKW40N120H3FKSA1; IGBT-TO544P521X1592X2557-3P
TC+1: IKW40N120H3FKSA1; IGBT-TO544P521X1592X2557-3P
TC-1: IKW40N120H3FKSA1; IGBT-TO544P521X1592X2557-3P
U18, U19: Wago_2604-3104; WAGO-26043104; Manufacturer_Part_Number 2604-3104

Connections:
+3.3V: K1.D1 (COM), R40.1, R48.1, SW1.1 (COM_1), SW1.2 (COM_2), SW2.1 (COM_1), SW2.2 (COM_2), SW3.1 (COM_1), SW3.2 (COM_2); also elsewhere on the board
+5V: DS1.2 (VDD), RV1.1; also elsewhere on the board
/CurrentMeasurement/L1 (out): RM1.1, U18.3, U18.4; also elsewhere on the board
/CurrentMeasurement/L2 (out): RM2.1, U18.5, U18.6; also elsewhere on the board
/CurrentMeasurement/L3 (out): RM3.1, U18.7, U18.8; also elsewhere on the board
/GateDriver1/OUTHS: J20.1, TA+1.1 (G); also elsewhere on the board
/GateDriver1/OUTLS: J16.1, TA-1.1 (G); also elsewhere on the board
/GateDriver2/OUTHS: J21.1, TB+1.1 (G); also elsewhere on the board
/GateDriver2/OUTLS: J17.1, TB-1.1 (G); also elsewhere on the board
/GateDriver3/OUTHS: J22.1, TC+1.1 (G); also elsewhere on the board
/GateDriver3/OUTLS: J18.1, TC-1.1 (G); also elsewhere on the board
COM (2): TA+1.3 (E), TA-1.2 (C); also elsewhere on the board
COM (4): TB+1.3 (E), TB-1.2 (C); also elsewhere on the board
COM (6): TC+1.3 (E), TC-1.2 (C); also elsewhere on the board
DC-LINK-VOLTAGE: R3_B1.1, R4_B1.2; also elsewhere on the board
Earth_Protective: H1.1, H1.2, H2.1, H2.2, H3.1, H3.2, U18.1, U18.2; also elsewhere on the board
GND: DS1.1 (VSS), K1.C1 (WIPER), K1.MH1, K1.MH2, R32.2, R35.2, R36.2, R37.1, R38.1, R39.1, R49.2, RV1.3; also elsewhere on the board
GND (dc-link): Cdc_link2.2, Cdc_link2.4, R4_B1.1, R_DC-link_4.2, TA-1.3 (E), TB-1.3 (E), TC-1.3 (E), U19.1, U19.2; also elsewhere on the board
I/O_DI_enc_A1: K1.A1 (CCW), R40.2; also elsewhere on the board
I/O_DI_enc_B1: K1.B1 (CW), R48.2; also elsewhere on the board
I/O_DI_enc_E1: K1.E1 (NO), R49.1; also elsewhere on the board
I/O_DI_sw-1: R37.2, SW1.3 (NO_1), SW1.4 (NO_2); also elsewhere on the board
I/O_DI_sw-2: R38.2, SW2.3 (NO_1), SW2.4 (NO_2); also elsewhere on the board
I/O_DI_sw-3: R39.2, SW3.3 (NO_1), SW3.4 (NO_2); also elsewhere on the board
I/O_DO_led-1: LED1.2 (A); also elsewhere on the board
I/O_DO_led-2: LED2.2 (A); also elsewhere on the board
I/O_DO_led-3: LED3.2 (A); also elsewhere on the board
I/O_I2C_SCL_display: DS1.14 (SCL); also elsewhere on the board
I/O_I2C_SDA_display: DS1.13 (SDA); also elsewhere on the board
unnamed: C_dc-link1.2, C_dc-link1.4, Cdc_link2.1, Cdc_link2.3, J12.1, R_DC-link_2.2, R_DC-link_3.1
unnamed: DS1.3 (V0), RV1.2
unnamed: LED1.1 (K), R32.1
unnamed: LED2.1 (K), R35.1
unnamed: LED3.1 (K), R36.1
unnamed: LM1.1, RM1.2
unnamed: LM1.2, LM2.2, LM3.2
unnamed: LM2.1, RM2.2
unnamed: LM3.1, RM3.2
unnamed: R1_B1.2, R2_B1.1
unnamed: R2_B1.2, R3_B1.2
unnamed: R_DC-link_1.2, R_DC-link_2.1
unnamed: R_DC-link_3.2, R_DC-link_4.1
TA+1_HS: C_dc-link1.1, C_dc-link1.3, J19.1, R1_B1.1, R_DC-link_1.1, TA+1.2 (C), TB+1.2 (C), TC+1.2 (C), U19.3, U19.4; also elsewhere on the board

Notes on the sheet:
DC-link capacitors
DC-link connector
DC-link current measurement
LCD DISPLAY
LEGGE INN FOOTPRINT OG 3D for potmeter
LED-DIODES
DC-link voltage measurement
Power Supplies
RED
GREEN
Heatsinks IGBT
ER PULL-DOWN resistorene riktig ohmsk verdi?
ROTARY ENCODER
YELLOW
MOUNTING HOLES
SWITCHES
Motor Control Card
VOLTAGE BRIDGE
ELECTRIC THREE PHASE INDUCTION MOTOR
Human Machine Interface

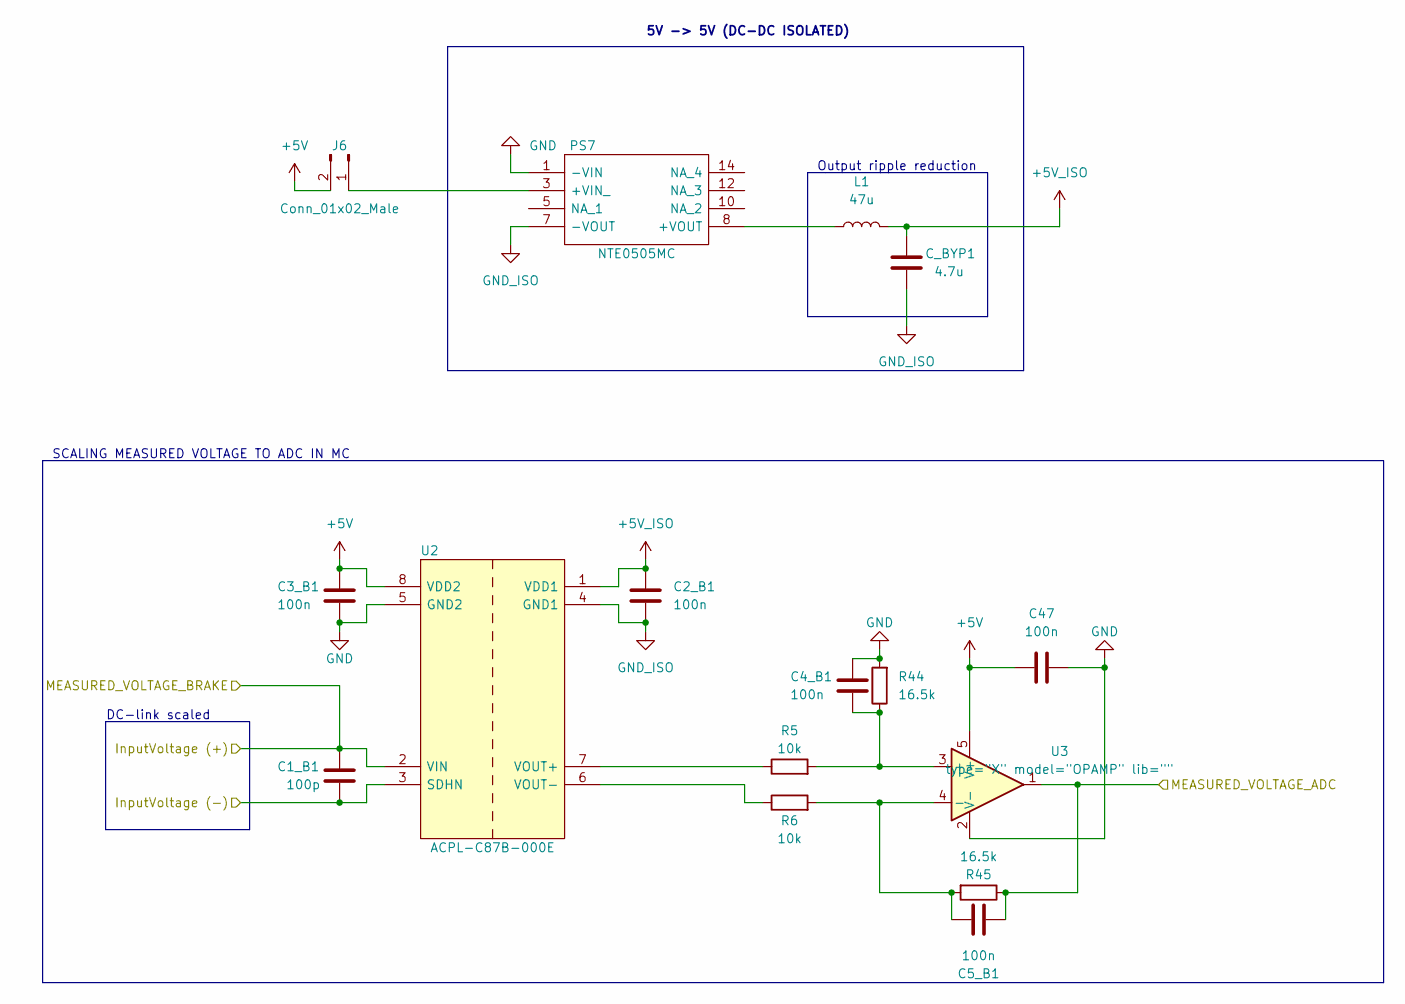
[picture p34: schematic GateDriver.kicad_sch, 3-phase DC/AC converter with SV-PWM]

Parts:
C1_B1: 100p; C_1206_3216Metric_Pad1.33x1.80mm_HandSolder
C2_B1, C3_B1, C4_B1, C5_B1, C47: 100n; C_1206_3216Metric_Pad1.33x1.80mm_HandSolder
C_BYP1: 4.7u; C_1206_3216Metric_Pad1.33x1.80mm_HandSolder
J6: Conn_01x02_Male; PinHeader_1x02_P1.00mm_Vertical
L1: 47u; L_2010_5025Metric_Pad1.52x2.65mm_HandSolder
PS7: NTE0505MC; DC-DC-NTE0505MC; Manufacturer_Part_Number NTE0505MC; Mouser Part Number 580-NTE0505MC
R5, R6: 10k; R_1206_3216Metric_Pad1.30x1.75mm_HandSolder
R44, R45: 16.5k; R_1206_3216Metric_Pad1.30x1.75mm_HandSolder
U2: ACPL-C87B-000E; ACPL-SOIC127P1150X331-8N; Manufacturer_Part_Number ACPL-C87B-000E; Mouser Part Number 630-ACPL-C87B-000E
U3: type="X" model="OPAMP" lib=""; OPA237-SOT95P280X145-5N

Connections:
+5V: C3_B1.1, C47.1, J6.2, U2.8 (VDD2), U3.5 (V+); also elsewhere on the board
+5V_ISO: C2_B1.1, C_BYP1.1, L1.2, U2.1 (VDD1)
DC-LINK-VOLTAGE: C1_B1.1, U2.2 (VIN); also elsewhere on the board
GND: C3_B1.2, C4_B1.2, C47.2, PS7.1 (-VIN), R44.2, U2.5 (GND2), U3.2 (V-); also elsewhere on the board
GND (dc-link): C1_B1.2, U2.3 (SDHN); also elsewhere on the board
GND_ISO: C2_B1.2, C_BYP1.2, PS7.7 (-VOUT), U2.4 (GND1)
I/O_AI_dc-link-voltage: C5_B1.1, R45.1, U3.1; also elsewhere on the board
unnamed: C4_B1.1, R5.2, R44.1, U3.3 (+)
unnamed: C5_B1.2, R6.2, R45.2, U3.4 (-)
unnamed: J6.1, PS7.3 (+VIN_)
unnamed: L1.1, PS7.8 (+VOUT)
unnamed: R5.1, U2.7 (VOUT+)
unnamed: R6.1, U2.6 (VOUT-)

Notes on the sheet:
DC-link scaled
Output ripple reduction
SCALING MEASURED VOLTAGE TO ADC IN MC
5V -> 5V (DC-DC ISOLATED)

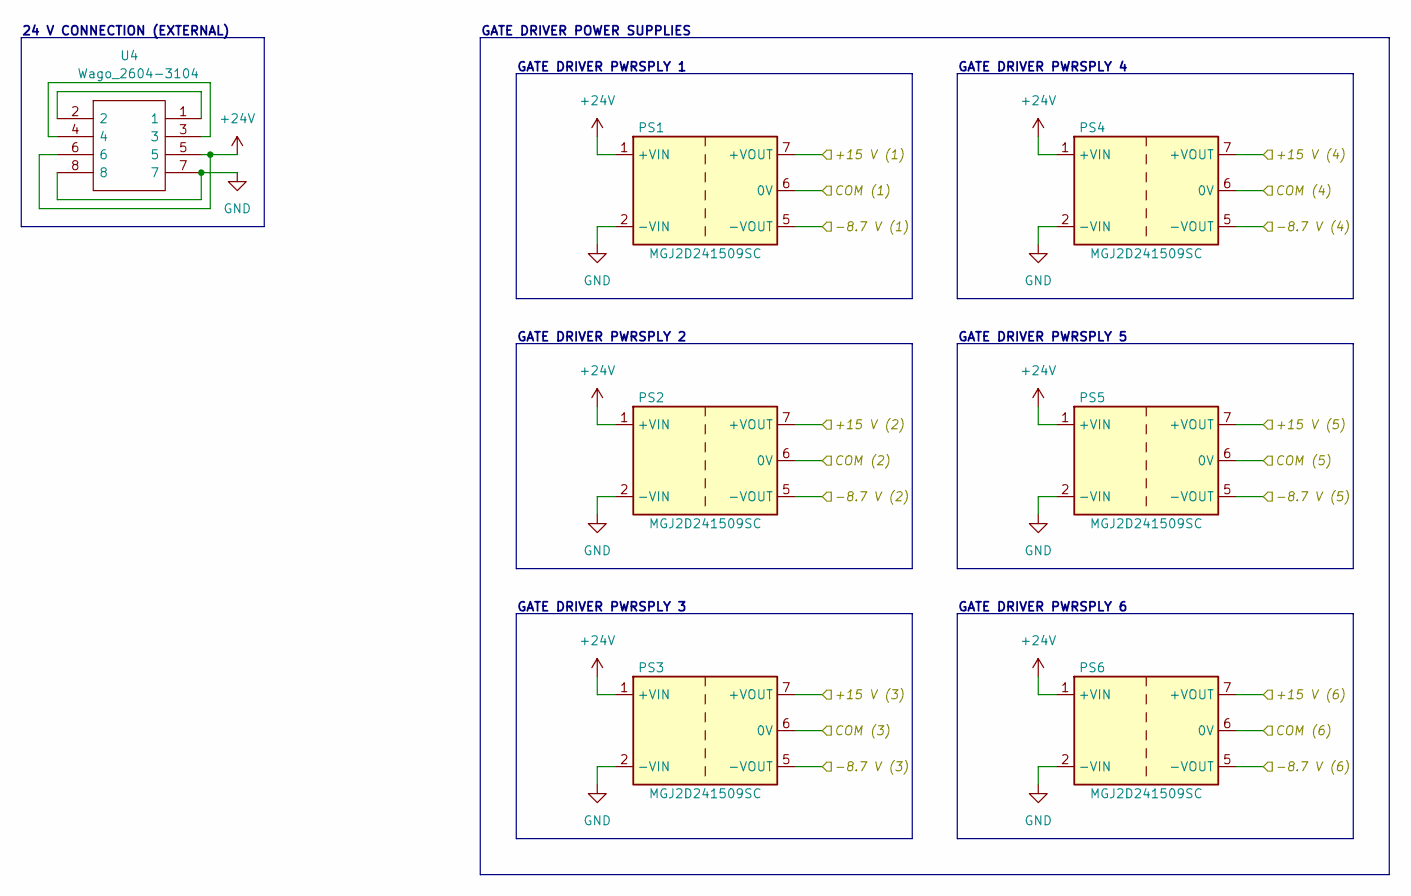
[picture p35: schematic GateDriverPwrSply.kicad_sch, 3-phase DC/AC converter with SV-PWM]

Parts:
PS1, PS2, PS3, PS4, PS5, PS6: MGJ2D241509SC; Converter_DCDC_Murata_MGJ2DxxxxxxSC_THT
U4: Wago_2604-3104; WAGO-26043104; Manufacturer_Part_Number 2604-3104

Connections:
+15 V (1): PS1.7 (+VOUT); also elsewhere on the board
+15 V (2): PS2.7 (+VOUT); also elsewhere on the board
+15 V (3): PS3.7 (+VOUT); also elsewhere on the board
+15 V (4): PS4.7 (+VOUT); also elsewhere on the board
+15 V (5): PS5.7 (+VOUT); also elsewhere on the board
+15 V (6): PS6.7 (+VOUT); also elsewhere on the board
+24V: PS1.1 (+VIN), PS2.1 (+VIN), PS3.1 (+VIN), PS4.1 (+VIN), PS5.1 (+VIN), PS6.1 (+VIN), U4.5, U4.6; also elsewhere on the board
-8.7 V (1): PS1.5 (-VOUT); also elsewhere on the board
-8.7 V (2): PS2.5 (-VOUT); also elsewhere on the board
-8.7 V (3): PS3.5 (-VOUT); also elsewhere on the board
-8.7 V (4): PS4.5 (-VOUT); also elsewhere on the board
-8.7 V (5): PS5.5 (-VOUT); also elsewhere on the board
-8.7 V (6): PS6.5 (-VOUT); also elsewhere on the board
COM (2): PS2.6 (0V); also elsewhere on the board
COM (4): PS4.6 (0V); also elsewhere on the board
COM (6): PS6.6 (0V); also elsewhere on the board
GND: PS1.2 (-VIN), PS2.2 (-VIN), PS3.2 (-VIN), PS4.2 (-VIN), PS5.2 (-VIN), PS6.2 (-VIN), U4.7, U4.8; also elsewhere on the board
GND (dc-link): PS1.6 (0V), PS3.6 (0V), PS5.6 (0V); also elsewhere on the board
unnamed: U4.1, U4.2
unnamed: U4.3, U4.4

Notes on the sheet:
GATE DRIVER PWRSPLY 6
GATE DRIVER PWRSPLY 5
GATE DRIVER POWER SUPPLIES
GATE DRIVER PWRSPLY 4
GATE DRIVER PWRSPLY 2
24 V CONNECTION (EXTERNAL)
GATE DRIVER PWRSPLY 3
GATE DRIVER PWRSPLY 1

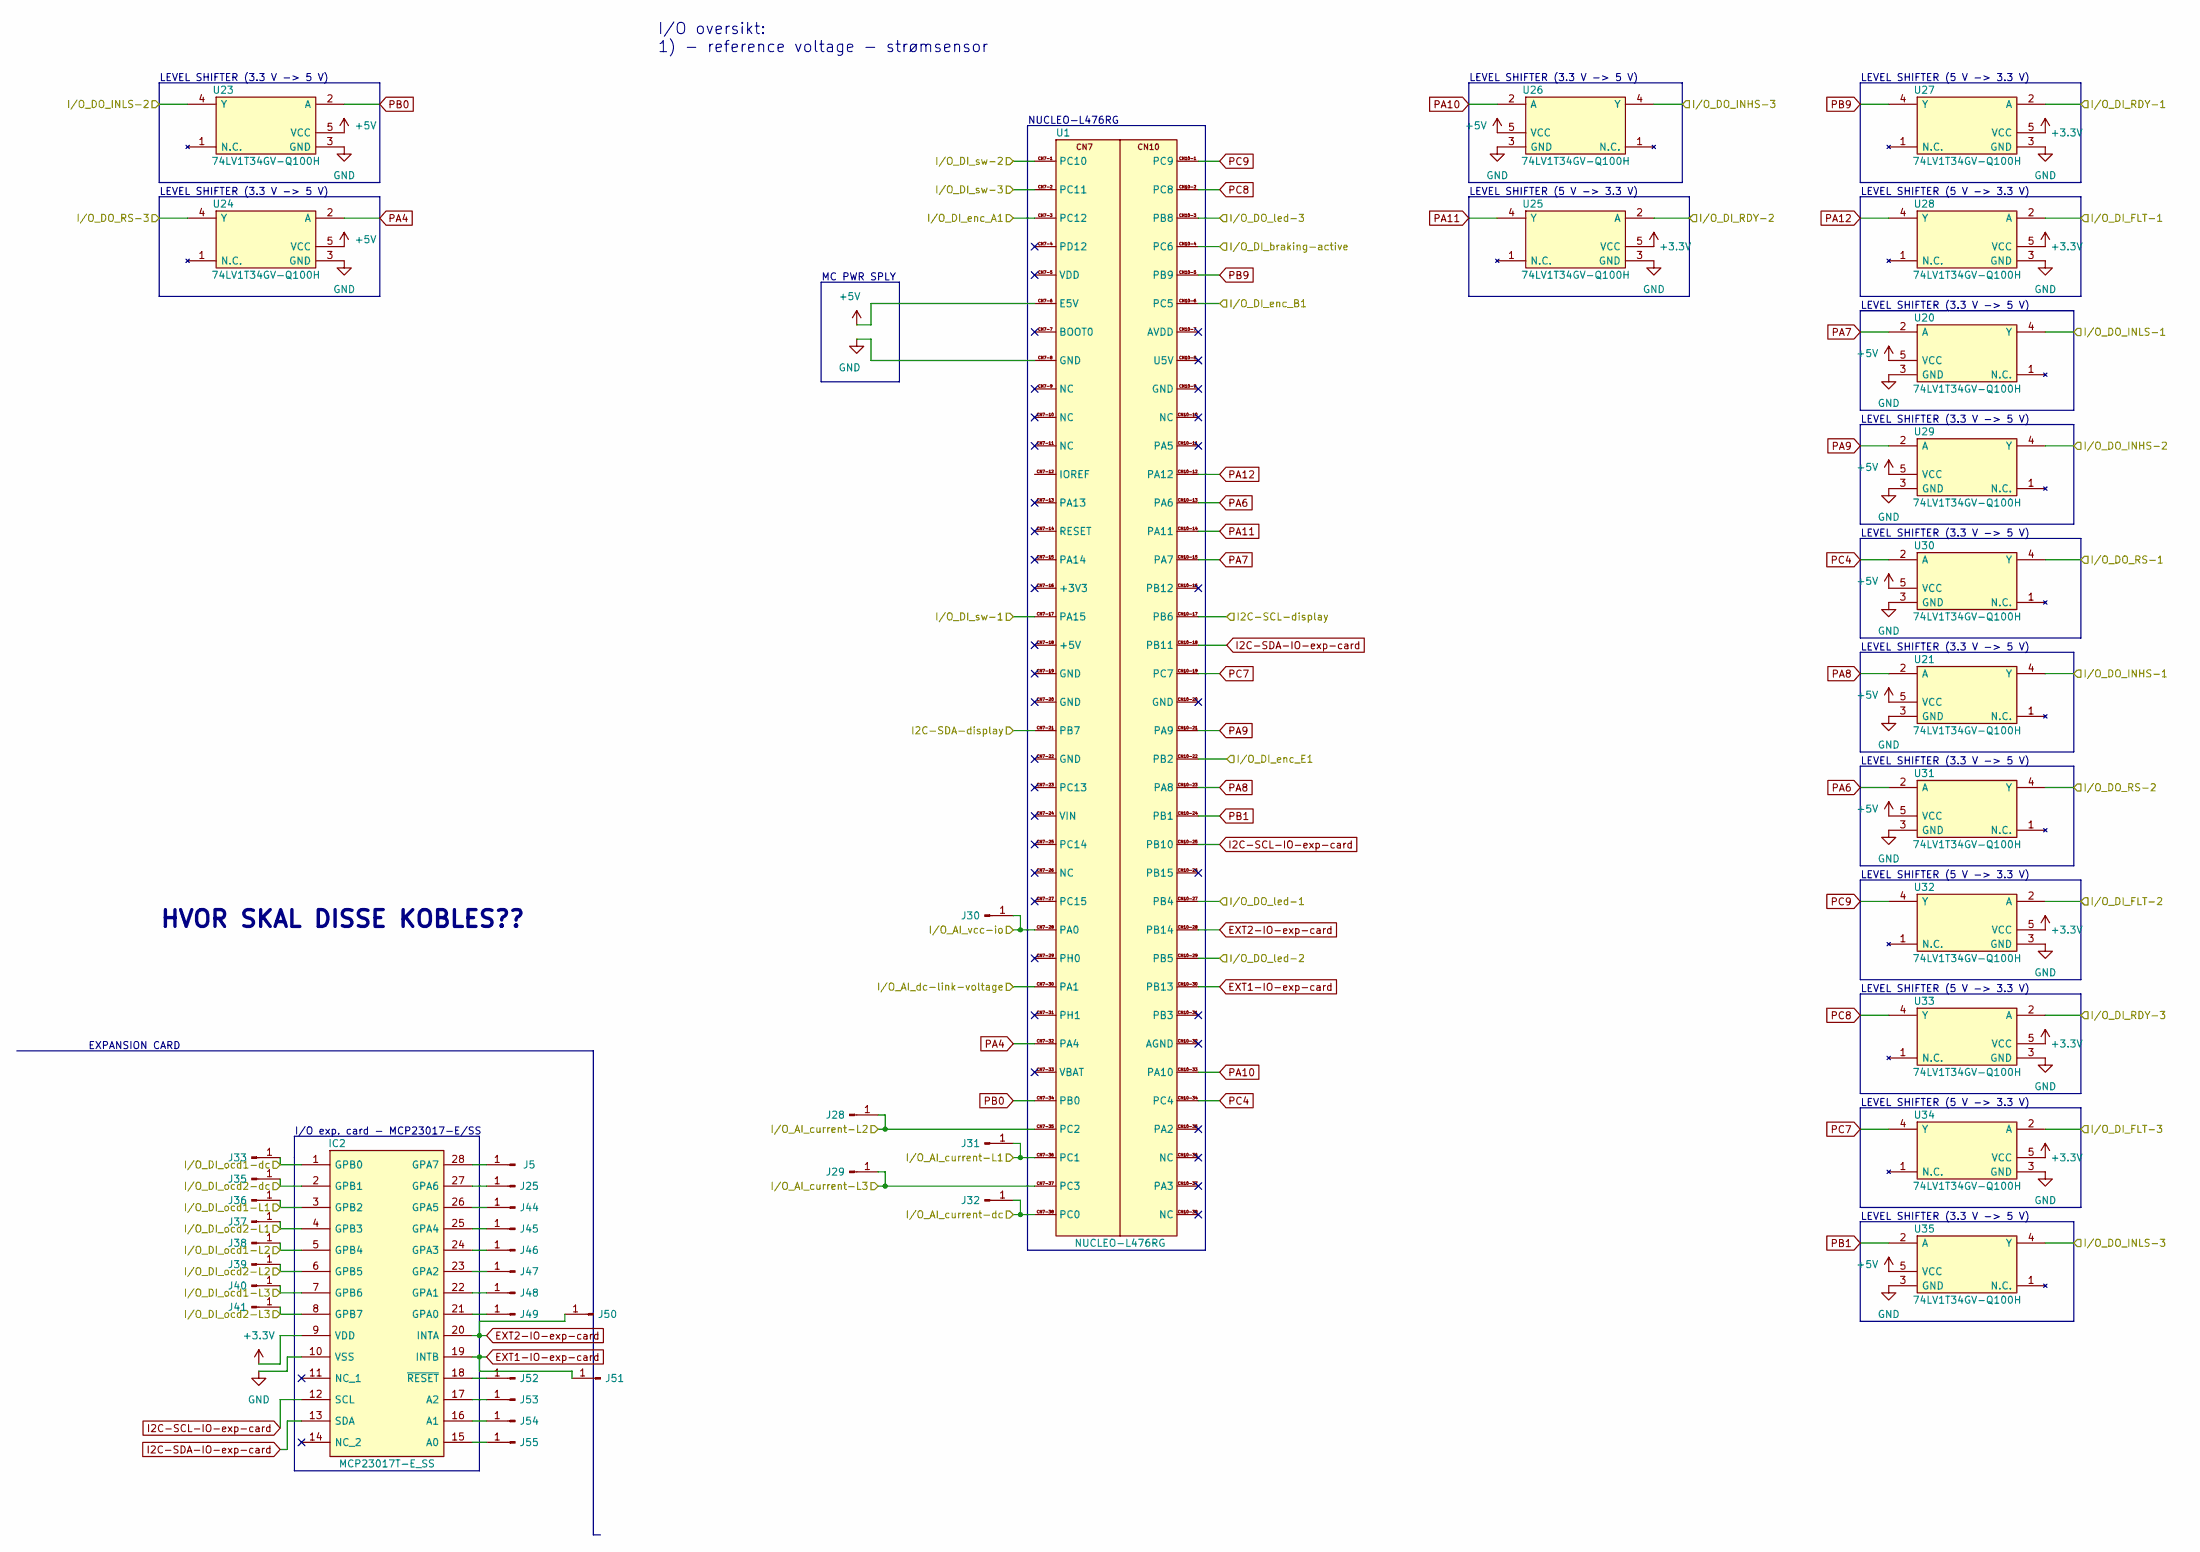
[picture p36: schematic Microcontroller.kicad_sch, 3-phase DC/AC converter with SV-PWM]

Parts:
IC2: MCP23017T-E_SS; MCP23017T-ESS-SOP65P780X200-28N; Manufacturer_Part_Number MCP23017T-E/SS; Mouser Part Number 579-MCP23017T-E/SS
J5, J25, J28, J29, J30, J31, J32, J33, J35, J36, J37, J38, J39, J40, J41, J44, J45, J46, J47, J48, J49, J50, J51, J52, J53, J54, J55: Conn_01x01_Male; PinHeader_1x01_P1.00mm_Vertical
U1: NUCLEO-L476RG; PCB-receptable Nucleo-L476RG
U20, U21, U23, U24, U25, U26, U27, U28, U29, U30, U31, U32, U33, U34, U35: 74LV1T34GV-Q100H; nexperia-SOT95P275X110-5N; Manufacturer_Part_Number 74LV1T34GV-Q100H; Mouser Part Number 771-74LV1T34GV-Q100H

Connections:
+3.3V: IC2.9 (VDD), U25.5 (VCC), U27.5 (VCC), U28.5 (VCC), U32.5 (VCC), U33.5 (VCC), U34.5 (VCC); also elsewhere on the board
+5V: U1.CN7-6 (E5V), U20.5 (VCC), U21.5 (VCC), U23.5 (VCC), U24.5 (VCC), U26.5 (VCC), U29.5 (VCC), U30.5 (VCC), U31.5 (VCC), U35.5 (VCC); also elsewhere on the board
EXT1-IO-exp-card: IC2.19 (INTB), J51.1, U1.CN10-30 (PB13)
EXT2-IO-exp-card: IC2.20 (INTA), J50.1, U1.CN10-28 (PB14)
GND: IC2.10 (VSS), U1.CN7-8 (GND), U20.3 (GND), U21.3 (GND), U23.3 (GND), U24.3 (GND), U25.3 (GND), U26.3 (GND), U27.3 (GND), U28.3 (GND), U29.3 (GND), U30.3 (GND), U31.3 (GND), U32.3 (GND), U33.3 (GND), U34.3 (GND), U35.3 (GND); also elsewhere on the board
I2C-SCL-IO-exp-card: IC2.12 (SCL), U1.CN10-25 (PB10)
I2C-SDA-IO-exp-card: IC2.13 (SDA), U1.CN10-18 (PB11)
I/O_AI_current-L1: J31.1, U1.CN7-36 (PC1); also elsewhere on the board
I/O_AI_current-L2: J28.1, U1.CN7-35 (PC2); also elsewhere on the board
I/O_AI_current-L3: J29.1, U1.CN7-37 (PC3); also elsewhere on the board
I/O_AI_current-dc: J32.1, U1.CN7-38 (PC0); also elsewhere on the board
I/O_AI_dc-link-voltage: U1.CN7-30 (PA1); also elsewhere on the board
I/O_AI_vcc-io: J30.1, U1.CN7-28 (PA0); also elsewhere on the board
I/O_DI_FLT-1: U28.2 (A); also elsewhere on the board
I/O_DI_FLT-2: U32.2 (A); also elsewhere on the board
I/O_DI_FLT-3: U34.2 (A); also elsewhere on the board
I/O_DI_RDY-1: U27.2 (A); also elsewhere on the board
I/O_DI_RDY-2: U25.2 (A); also elsewhere on the board
I/O_DI_RDY-3: U33.2 (A); also elsewhere on the board
I/O_DI_braking-active: U1.CN10-4 (PC6); also elsewhere on the board
I/O_DI_enc_A1: U1.CN7-3 (PC12); also elsewhere on the board
I/O_DI_enc_B1: U1.CN10-6 (PC5); also elsewhere on the board
I/O_DI_enc_E1: U1.CN10-22 (PB2); also elsewhere on the board
I/O_DI_ocd1-L1: IC2.3 (GPB2), J36.1; also elsewhere on the board
I/O_DI_ocd1-L2: IC2.5 (GPB4), J38.1; also elsewhere on the board
I/O_DI_ocd1-L3: IC2.7 (GPB6), J40.1; also elsewhere on the board
I/O_DI_ocd1-dc: IC2.1 (GPB0), J33.1; also elsewhere on the board
I/O_DI_ocd2-L1: IC2.4 (GPB3), J37.1; also elsewhere on the board
I/O_DI_ocd2-L2: IC2.6 (GPB5), J39.1; also elsewhere on the board
I/O_DI_ocd2-L3: IC2.8 (GPB7), J41.1; also elsewhere on the board
I/O_DI_ocd2-dc: IC2.2 (GPB1), J35.1; also elsewhere on the board
I/O_DI_sw-1: U1.CN7-17 (PA15); also elsewhere on the board
I/O_DI_sw-2: U1.CN7-1 (PC10); also elsewhere on the board
I/O_DI_sw-3: U1.CN7-2 (PC11); also elsewhere on the board
I/O_DO_INHS-1: U21.4 (Y); also elsewhere on the board
I/O_DO_INHS-2: U29.4 (Y); also elsewhere on the board
I/O_DO_INHS-3: U26.4 (Y); also elsewhere on the board
I/O_DO_INLS-1: U20.4 (Y); also elsewhere on the board
I/O_DO_INLS-2: U23.4 (Y); also elsewhere on the board
I/O_DO_INLS-3: U35.4 (Y); also elsewhere on the board
I/O_DO_RS-1: U30.4 (Y); also elsewhere on the board
I/O_DO_RS-2: U31.4 (Y); also elsewhere on the board
I/O_DO_RS-3: U24.4 (Y); also elsewhere on the board
I/O_DO_led-1: U1.CN10-27 (PB4); also elsewhere on the board
I/O_DO_led-2: U1.CN10-29 (PB5); also elsewhere on the board
I/O_DO_led-3: U1.CN10-3 (PB8); also elsewhere on the board
I/O_I2C_SCL_display: U1.CN10-17 (PB6); also elsewhere on the board
I/O_I2C_SDA_display: U1.CN7-21 (PB7); also elsewhere on the board
unnamed: IC2.15 (A0), J55.1
unnamed: IC2.16 (A1), J54.1
unnamed: IC2.17 (A2), J53.1
unnamed: IC2.18 (~RESET), J52.1
unnamed: IC2.21 (GPA0), J49.1
unnamed: IC2.22 (GPA1), J48.1
unnamed: IC2.23 (GPA2), J47.1
unnamed: IC2.24 (GPA3), J46.1
unnamed: IC2.25 (GPA4), J45.1
unnamed: IC2.26 (GPA5), J44.1
unnamed: IC2.27 (GPA6), J25.1
unnamed: IC2.28 (GPA7), J5.1
PA4: U1.CN7-32 (PA4), U24.2 (A)
PA6: U1.CN10-13 (PA6), U31.2 (A)
PA7: U1.CN10-15 (PA7), U20.2 (A)
PA8: U1.CN10-23 (PA8), U21.2 (A)
PA9: U1.CN10-21 (PA9), U29.2 (A)
PA10: U1.CN10-33 (PA10), U26.2 (A)
PA11: U1.CN10-14 (PA11), U25.4 (Y)
PA12: U1.CN10-12 (PA12), U28.4 (Y)
PB0: U1.CN7-34 (PB0), U23.2 (A)
PB1: U1.CN10-24 (PB1), U35.2 (A)
PB9: U1.CN10-5 (PB9), U27.4 (Y)
PC4: U1.CN10-34 (PC4), U30.2 (A)
PC7: U1.CN10-19 (PC7), U34.4 (Y)
PC8: U1.CN10-2 (PC8), U33.4 (Y)
PC9: U1.CN10-1 (PC9), U32.4 (Y)

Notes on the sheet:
LEVEL SHIFTER (3.3 V -> 5 V)
NUCLEO-L476RG
LEVEL SHIFTER (5 V -> 3.3 V)
HVOR SKAL DISSE KOBLES??
MC PWR SPLY
I/O exp. card - MCP23017-E/SS
EXPANSION CARD
I/O oversikt: 1) - reference voltage - strømsensor

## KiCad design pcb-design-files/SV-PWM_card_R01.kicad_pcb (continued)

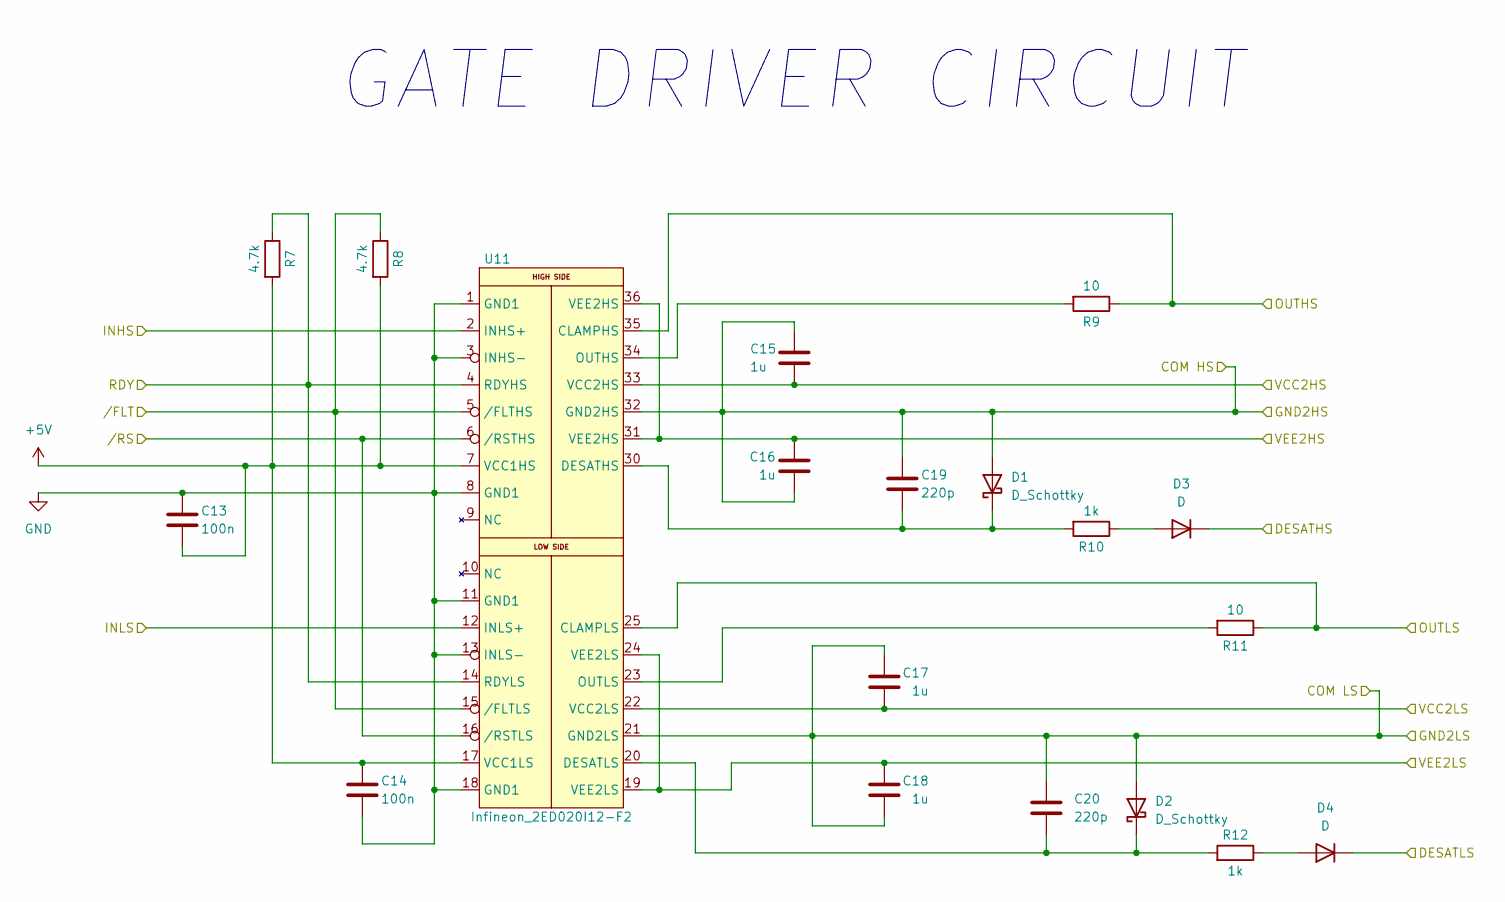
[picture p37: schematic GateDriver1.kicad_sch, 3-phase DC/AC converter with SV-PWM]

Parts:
C13, C14: 100n; C_1206_3216Metric_Pad1.33x1.80mm_HandSolder
C15, C16, C17, C18: 1u; C_1206_3216Metric_Pad1.33x1.80mm_HandSolder
C19, C20: 220p; C_1206_3216Metric_Pad1.33x1.80mm_HandSolder
D1, D2: D_Schottky; Schottky-BAT165AX
D3, D4: D; Diode-SMBJ50CA
R7, R8: 4.7k; R_1206_3216Metric_Pad1.30x1.75mm_HandSolder
R9, R11: 10; R_1206_3216Metric_Pad1.30x1.75mm_HandSolder
R10, R12: 1k; R_1206_3216Metric_Pad1.30x1.75mm_HandSolder
U11: Infineon_2ED020I12-F2; GateDriver-2ED020I12F2XUMA1

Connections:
+5V: C13.1, C14.2, R7.2, R8.2, U11.7 (VCC1HS), U11.17 (VCC1LS); also elsewhere on the board
+15 V (1): C17.1, U11.22 (VCC2LS); also elsewhere on the board
+15 V (2): C15.2, U11.33 (VCC2HS); also elsewhere on the board
-8.7 V (1): C18.1, U11.19 (VEE2LS), U11.24 (VEE2LS); also elsewhere on the board
-8.7 V (2): C16.1, U11.31 (VEE2HS), U11.36 (VEE2HS); also elsewhere on the board
/GateDriver1/OUTHS: R9.1, U11.35 (CLAMPHS); also elsewhere on the board
/GateDriver1/OUTLS: R11.1, U11.25 (CLAMPLS); also elsewhere on the board
COM (2): C15.1, C16.2, C19.2, D1.2 (A), D4.1 (K), U11.32 (GND2HS); also elsewhere on the board
GND: C13.2, C14.1, U11.1 (GND1), U11.3 (INHS-), U11.8 (GND1), U11.11 (GND1), U11.13 (INLS-), U11.18 (GND1); also elsewhere on the board
GND (dc-link): C17.2, C18.2, C20.2, D2.2 (A), U11.21 (GND2LS); also elsewhere on the board
I/O_DI_FLT-1: R8.1, U11.5 (/FLTHS), U11.15 (/FLTLS); also elsewhere on the board
I/O_DI_RDY-1: R7.1, U11.4 (RDYHS), U11.14 (RDYLS); also elsewhere on the board
I/O_DO_INHS-1: U11.2 (INHS+); also elsewhere on the board
I/O_DO_INLS-1: U11.12 (INLS+); also elsewhere on the board
I/O_DO_RS-1: U11.6 (/RSTHS), U11.16 (/RSTLS); also elsewhere on the board
unnamed: C19.1, D1.1 (K), R10.2, U11.30 (DESATHS)
unnamed: C20.1, D2.1 (K), R12.2, U11.20 (DESATLS)
unnamed: D3.2 (A), R10.1
unnamed: D4.2 (A), R12.1
unnamed: R9.2, U11.34 (OUTHS)
unnamed: R11.2, U11.23 (OUTLS)
TA+1_HS: D3.1 (K); also elsewhere on the board

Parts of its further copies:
C21, C22, C29, C30: 100n; C_1206_3216Metric_Pad1.33x1.80mm_HandSolder
C23, C24, C25, C26, C31, C32, C33, C34: 1u; C_1206_3216Metric_Pad1.33x1.80mm_HandSolder
C27, C28, C35, C36: 220p; C_1206_3216Metric_Pad1.33x1.80mm_HandSolder
D5, D6, D9, D10: D_Schottky; Schottky-BAT165AX
D7, D8, D11, D12: D; Diode-SMBJ50CA
R13, R14, R19, R20: 4.7k; R_1206_3216Metric_Pad1.30x1.75mm_HandSolder
R15, R17, R21, R23: 10; R_1206_3216Metric_Pad1.30x1.75mm_HandSolder
R16, R18, R22, R24: 1k; R_1206_3216Metric_Pad1.30x1.75mm_HandSolder
U12, U13: Infineon_2ED020I12-F2; GateDriver-2ED020I12F2XUMA1

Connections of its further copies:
+5V: C21.1, C22.2, C29.1, C30.2, R13.2, R14.2, R19.2, R20.2, U12.7 (VCC1HS), U12.17 (VCC1LS), U13.7 (VCC1HS), U13.17 (VCC1LS); also elsewhere on the board
+15 V (3): C25.1, U12.22 (VCC2LS); also elsewhere on the board
+15 V (4): C23.2, U12.33 (VCC2HS); also elsewhere on the board
+15 V (5): C33.1, U13.22 (VCC2LS); also elsewhere on the board
+15 V (6): C31.2, U13.33 (VCC2HS); also elsewhere on the board
-8.7 V (3): C26.1, U12.19 (VEE2LS), U12.24 (VEE2LS); also elsewhere on the board
-8.7 V (4): C24.1, U12.31 (VEE2HS), U12.36 (VEE2HS); also elsewhere on the board
-8.7 V (5): C34.1, U13.19 (VEE2LS), U13.24 (VEE2LS); also elsewhere on the board
-8.7 V (6): C32.1, U13.31 (VEE2HS), U13.36 (VEE2HS); also elsewhere on the board
/GateDriver2/OUTHS: R15.1, U12.35 (CLAMPHS); also elsewhere on the board
/GateDriver2/OUTLS: R17.1, U12.25 (CLAMPLS); also elsewhere on the board
/GateDriver3/OUTHS: R21.1, U13.35 (CLAMPHS); also elsewhere on the board
/GateDriver3/OUTLS: R23.1, U13.25 (CLAMPLS); also elsewhere on the board
COM (4): C23.1, C24.2, C27.2, D5.2 (A), D8.1 (K), U12.32 (GND2HS); also elsewhere on the board
COM (6): C31.1, C32.2, C35.2, D9.2 (A), D12.1 (K), U13.32 (GND2HS); also elsewhere on the board
GND: C21.2, C22.1, C29.2, C30.1, U12.1 (GND1), U12.3 (INHS-), U12.8 (GND1), U12.11 (GND1), U12.13 (INLS-), U12.18 (GND1), U13.1 (GND1), U13.3 (INHS-), U13.8 (GND1), U13.11 (GND1), U13.13 (INLS-), U13.18 (GND1); also elsewhere on the board
GND (dc-link): C25.2, C26.2, C28.2, C33.2, C34.2, C36.2, D6.2 (A), D10.2 (A), U12.21 (GND2LS), U13.21 (GND2LS); also elsewhere on the board
I/O_DI_FLT-2: R14.1, U12.5 (/FLTHS), U12.15 (/FLTLS); also elsewhere on the board
I/O_DI_FLT-3: R20.1, U13.5 (/FLTHS), U13.15 (/FLTLS); also elsewhere on the board
I/O_DI_RDY-2: R13.1, U12.4 (RDYHS), U12.14 (RDYLS); also elsewhere on the board
I/O_DI_RDY-3: R19.1, U13.4 (RDYHS), U13.14 (RDYLS); also elsewhere on the board
I/O_DO_INHS-2: U12.2 (INHS+); also elsewhere on the board
I/O_DO_INHS-3: U13.2 (INHS+); also elsewhere on the board
I/O_DO_INLS-2: U12.12 (INLS+); also elsewhere on the board
I/O_DO_INLS-3: U13.12 (INLS+); also elsewhere on the board
I/O_DO_RS-2: U12.6 (/RSTHS), U12.16 (/RSTLS); also elsewhere on the board
I/O_DO_RS-3: U13.6 (/RSTHS), U13.16 (/RSTLS); also elsewhere on the board
unnamed: C27.1, D5.1 (K), R16.2, U12.30 (DESATHS)
unnamed: C28.1, D6.1 (K), R18.2, U12.20 (DESATLS)
unnamed: C35.1, D9.1 (K), R22.2, U13.30 (DESATHS)
unnamed: C36.1, D10.1 (K), R24.2, U13.20 (DESATLS)
unnamed: D7.2 (A), R16.1
unnamed: D8.2 (A), R18.1
unnamed: D11.2 (A), R22.1
unnamed: D12.2 (A), R24.1
unnamed: R15.2, U12.34 (OUTHS)
unnamed: R17.2, U12.23 (OUTLS)
unnamed: R21.2, U13.34 (OUTHS)
unnamed: R23.2, U13.23 (OUTLS)
TA+1_HS: D7.1 (K), D11.1 (K); also elsewhere on the board

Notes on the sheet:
GATE DRIVER CIRCUIT

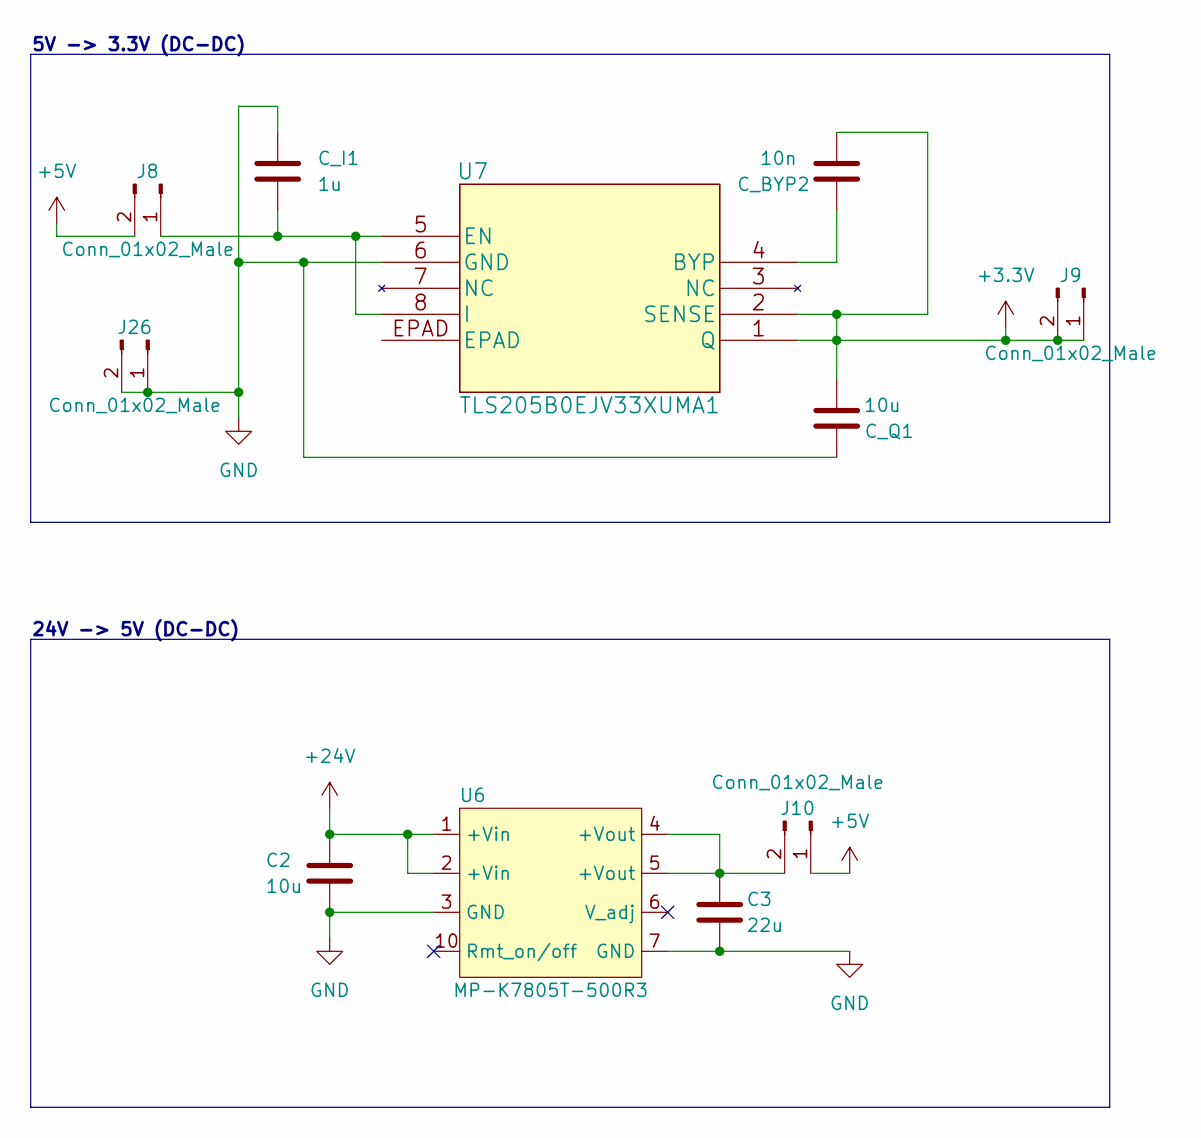
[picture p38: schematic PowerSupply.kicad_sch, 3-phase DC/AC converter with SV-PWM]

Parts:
C2: 10u; C_1206_3216Metric_Pad1.33x1.80mm_HandSolder
C3: 22u; C_1206_3216Metric_Pad1.33x1.80mm_HandSolder
C_BYP2: 10n; C_1206_3216Metric_Pad1.33x1.80mm_HandSolder
C_I1: 1u; C_1206_3216Metric_Pad1.33x1.80mm_HandSolder
C_Q1: 10u; C_1206_3216Metric_Pad1.33x1.80mm_HandSolder
J8, J9, J10, J26: Conn_01x02_Male; PinHeader_1x02_P1.00mm_Vertical
U6: MP-K7805T-500R3; Multicomp-MPK7803T500R3
U7: TLS205B0EJV33XUMA1; TLS205B0EJV33XUMA1-SOIC127P600X170-9N

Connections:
+3.3V: C_BYP2.2, C_Q1.2, J9.1, J9.2, U7.1 (Q), U7.2 (SENSE); also elsewhere on the board
+5V: J8.2, J10.1; also elsewhere on the board
+24V: C2.1, U6.1 (+Vin), U6.2 (+Vin); also elsewhere on the board
GND: C2.2, C3.2, C_I1.2, C_Q1.1, J26.1, J26.2, U6.3 (GND), U6.7 (GND), U7.6 (GND); also elsewhere on the board
unnamed: C3.1, J10.2, U6.4 (+Vout), U6.5 (+Vout)
unnamed: C_BYP2.1, U7.4 (BYP)
unnamed: C_I1.1, J8.1, U7.5 (EN), U7.8 (I)

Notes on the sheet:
24V -> 5V (DC-DC)
5V -> 3.3V (DC-DC)

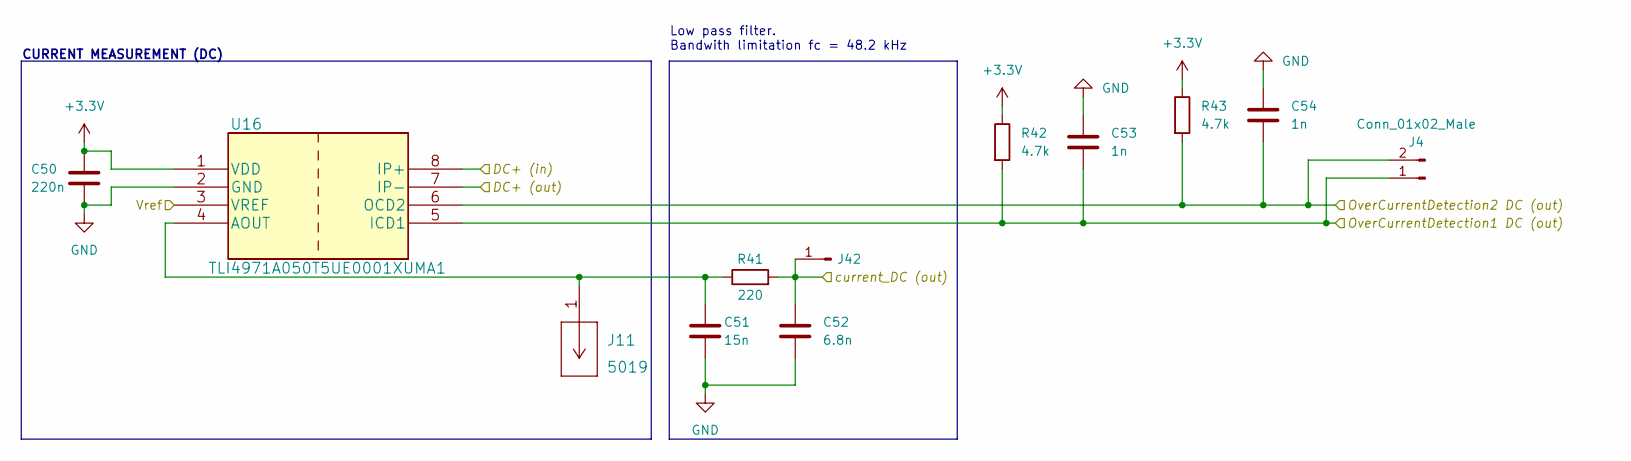
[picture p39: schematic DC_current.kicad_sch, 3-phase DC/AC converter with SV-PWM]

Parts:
C50: 220n; C_1206_3216Metric_Pad1.33x1.80mm_HandSolder
C51: 15n; C_1206_3216Metric_Pad1.33x1.80mm_HandSolder
C52: 6.8n; C_1206_3216Metric_Pad1.33x1.80mm_HandSolder
C53, C54: 1n; C_1206_3216Metric_Pad1.33x1.80mm_HandSolder
J4: Conn_01x02_Male; PinHeader_1x02_P1.00mm_Vertical
J11: 5019; Keystone-5019
J42: Conn_01x01_Male; PinHeader_1x01_P1.00mm_Vertical
R41: 220; R_1206_3216Metric_Pad1.30x1.75mm_HandSolder
R42, R43: 4.7k; R_1206_3216Metric_Pad1.30x1.75mm_HandSolder
U16: TLI4971A050T5UE0001XUMA1

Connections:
+3.3V: C50.2, R42.1, R43.1, U16.1 (VDD), U16.9; also elsewhere on the board
/Braking/DC-LINK (+): U16.8 (IP+); also elsewhere on the board
GND: C50.1, C51.2, C52.2, C53.1, C54.1, U16.2 (GND); also elsewhere on the board
I/O_AI_current-dc: C52.1, J42.1, R41.2; also elsewhere on the board
I/O_AI_vcc-io: U16.3 (VREF); also elsewhere on the board
I/O_DI_ocd1-dc: C53.2, J4.1, R42.2, U16.5 (ICD1); also elsewhere on the board
I/O_DI_ocd2-dc: C54.2, J4.2, R43.2, U16.6 (OCD2); also elsewhere on the board
unnamed: C51.1, J11.1, R41.1, U16.4 (AOUT)
TA+1_HS: U16.7 (IP-); also elsewhere on the board

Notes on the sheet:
Low pass filter. Bandwith limitation fc = 48.2 kHz
CURRENT MEASUREMENT (DC)

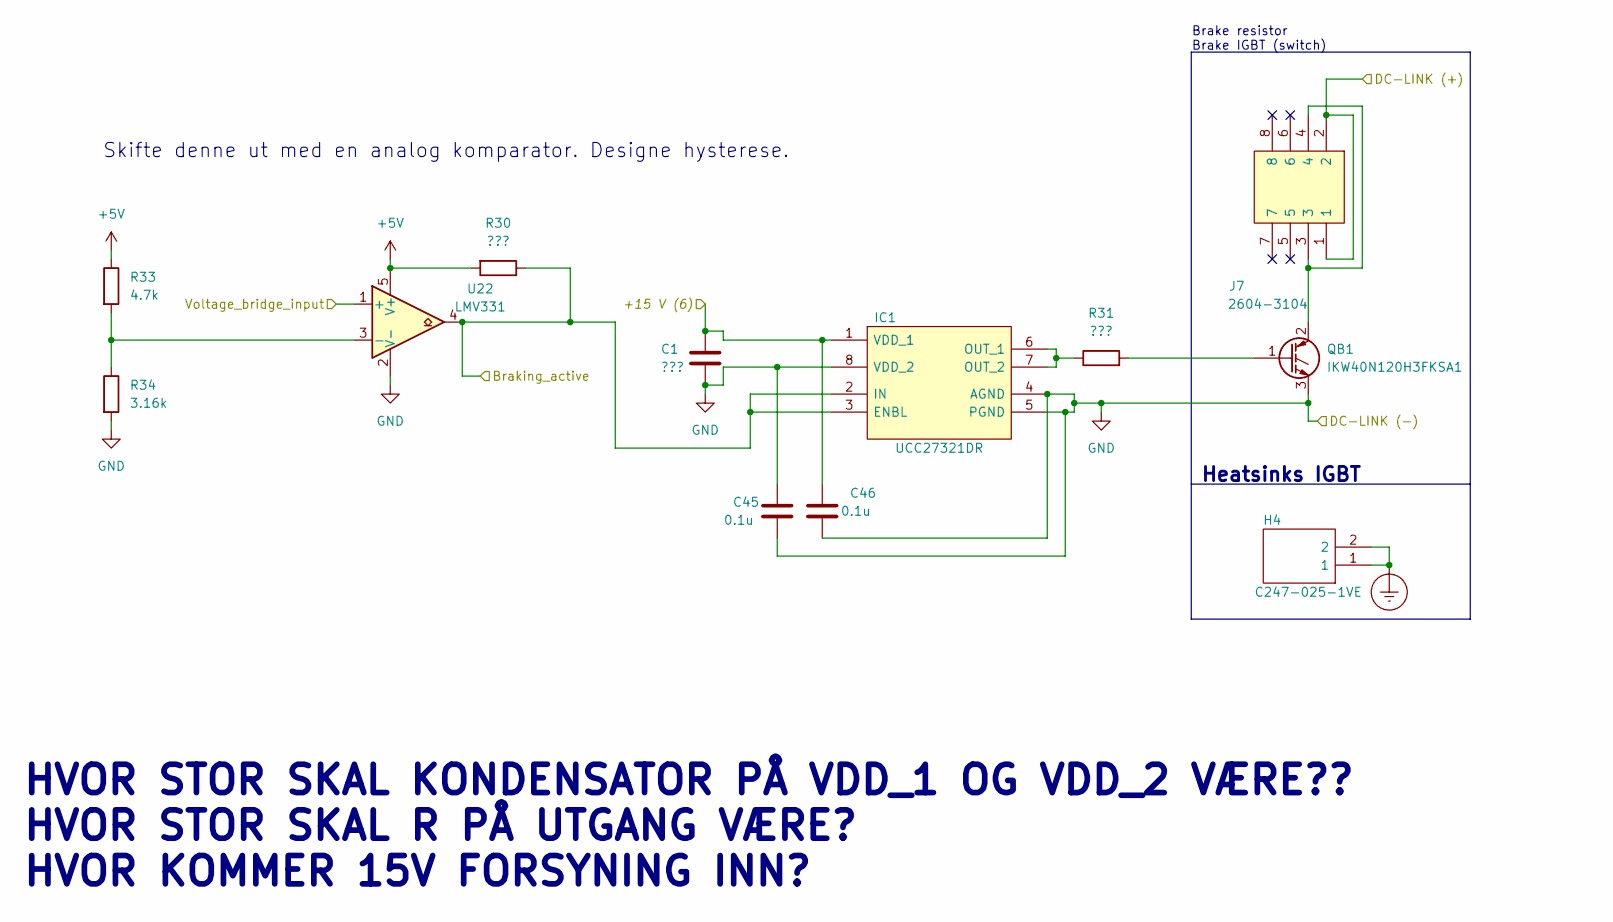
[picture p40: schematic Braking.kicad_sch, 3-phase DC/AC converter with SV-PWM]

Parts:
C1: ???; C_1206_3216Metric_Pad1.33x1.80mm_HandSolder
C45, C46: 0.1u; C_1206_3216Metric_Pad1.33x1.80mm_HandSolder
H4: C247-025-1VE; Heatsink_brake_C2470251VE; Manufacturer_Part_Number C247-025-1VE; Mouser Part Number 588-C247-025-1VE
IC1: UCC27321DR; UCC27321DR_SOIC127P600X175-8N; Manufacturer_Part_Number UCC27321DR; Mouser Part Number 595-UCC27321DR
J7: 2604-3104; WAGO-26043104; Manufacturer_Part_Number 2604-3104
QB1: IKW40N120H3FKSA1; IGBT-TO544P521X1592X2557-3P
R30, R31: ???; R_1206_3216Metric_Pad1.30x1.75mm_HandSolder
R33: 4.7k; R_1206_3216Metric_Pad1.30x1.75mm_HandSolder
R34: 3.16k; R_1206_3216Metric_Pad1.30x1.75mm_HandSolder
U22: LMV331; LMV331M5_SOT95P280X145-5N

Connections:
+5V: R30.2, R33.1, U22.5 (V+); also elsewhere on the board
+15 V (6): C1.1, C46.1, IC1.1 (VDD_1); also elsewhere on the board
/Braking/DC-LINK (+): J7.1, J7.2; also elsewhere on the board
DC-LINK-VOLTAGE: U22.1 (+); also elsewhere on the board
Earth_Protective: H4.1, H4.2; also elsewhere on the board
GND (dc-link): C1.2, C45.1, C45.2, C46.2, IC1.4 (AGND), IC1.5 (PGND), IC1.8 (VDD_2), QB1.3 (E), R34.2, U22.2 (V-); also elsewhere on the board
I/O_DI_braking-active: IC1.2 (IN), IC1.3 (ENBL), R30.1, U22.4; also elsewhere on the board
unnamed: IC1.6 (OUT_1), IC1.7 (OUT_2), R31.1
unnamed: J7.3, J7.4, QB1.2 (C)
unnamed: QB1.1 (G), R31.2
unnamed: R33.2, R34.1, U22.3 (-)

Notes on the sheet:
Skifte denne ut med en analog komparator. Designe hysterese.
HVOR STOR SKAL KONDENSATOR PÅ VDD_1 OG VDD_2 VÆRE?? HVOR STOR SKAL R PÅ UTGANG VÆRE? HVOR KOMMER 15V FORSYNING INN?
Brake resistor Brake IGBT (switch)
Heatsinks IGBT

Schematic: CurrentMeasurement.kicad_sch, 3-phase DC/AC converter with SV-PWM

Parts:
C4, C5, C6: 220n; C_1206_3216Metric_Pad1.33x1.80mm_HandSolder
C7, C8, C9, C10, C11, C12: 1n; C_1206_3216Metric_Pad1.33x1.80mm_HandSolder
C37, C38, C42, C43, C44: 6.8n; C_1206_3216Metric_Pad1.33x1.80mm_HandSolder
C39, C40, C41: 15n; C_1206_3216Metric_Pad1.33x1.80mm_HandSolder
J1, J2, J3, J27: Conn_01x02_Male; PinHeader_1x02_P1.00mm_Vertical
J13, J14, J15: 5019; Keystone-5019
J23, J24, J34, J43: Conn_01x01_Male; PinHeader_1x01_P1.00mm_Vertical
R1, R2, R3, R4, R46, R47: 4.7k; R_1206_3216Metric_Pad1.30x1.75mm_HandSolder
R25, R26: 1k; R_1206_3216Metric_Pad1.30x1.75mm_HandSolder
R27, R28, R29: 220; R_1206_3216Metric_Pad1.30x1.75mm_HandSolder
U8, U9, U10: TLI4971A050T5UE0001XUMA1

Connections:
+3.3V: C4.1, C5.1, C6.1, J27.1, R1.1, R2.1, R3.1, R4.1, R25.1, R46.1, R47.1, U8.1 (VDD), U8.9, U9.1 (VDD), U9.9, U10.1 (VDD), U10.9; also elsewhere on the board
/CurrentMeasurement/L1 (out): U10.7 (IP-); also elsewhere on the board
/CurrentMeasurement/L2 (out): U9.7 (IP-); also elsewhere on the board
/CurrentMeasurement/L3 (out): U8.7 (IP-); also elsewhere on the board
COM (2): U10.8 (IP+); also elsewhere on the board
COM (4): U9.8 (IP+); also elsewhere on the board
COM (6): U8.8 (IP+); also elsewhere on the board
GND: C4.2, C5.2, C6.2, C7.1, C8.1, C9.1, C10.1, C11.1, C12.1, C37.2, C38.2, C39.2, C40.2, C41.2, C42.2, C43.2, C44.2, J27.2, R26.2, U8.2 (GND), U9.2 (GND), U10.2 (GND); also elsewhere on the board
I/O_AI_current-L1: C42.1, J23.1, R27.2; also elsewhere on the board
I/O_AI_current-L2: C43.1, J24.1, R28.2; also elsewhere on the board
I/O_AI_current-L3: C44.1, J34.1, R29.2; also elsewhere on the board
I/O_AI_vcc-io: C37.1, C38.1, J43.1, R25.2, R26.1, U8.3 (VREF), U9.3 (VREF), U10.3 (VREF); also elsewhere on the board
I/O_DI_ocd1-L1: C7.2, J1.1, R1.2, U10.5 (ICD1); also elsewhere on the board
I/O_DI_ocd1-L2: C8.2, J2.1, R2.2, U9.5 (ICD1); also elsewhere on the board
I/O_DI_ocd1-L3: C9.2, J3.1, R3.2, U8.5 (ICD1); also elsewhere on the board
I/O_DI_ocd2-L1: C10.2, J1.2, R4.2, U10.6 (OCD2); also elsewhere on the board
I/O_DI_ocd2-L2: C11.2, J2.2, R46.2, U9.6 (OCD2); also elsewhere on the board
I/O_DI_ocd2-L3: C12.2, J3.2, R47.2, U8.6 (OCD2); also elsewhere on the board
unnamed: C39.1, J13.1, R27.1, U10.4 (AOUT)
unnamed: C40.1, J14.1, R28.1, U9.4 (AOUT)
unnamed: C41.1, J15.1, R29.1, U8.4 (AOUT)

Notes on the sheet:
Power supply from jumpers
Low pass filter. Bandwith limitation fc = 48.2 kHz
CURRENT MEASUREMENTS: L1-L2-L3
REFERENCE VOLTAGE - CURRENT CHIPS / ADC

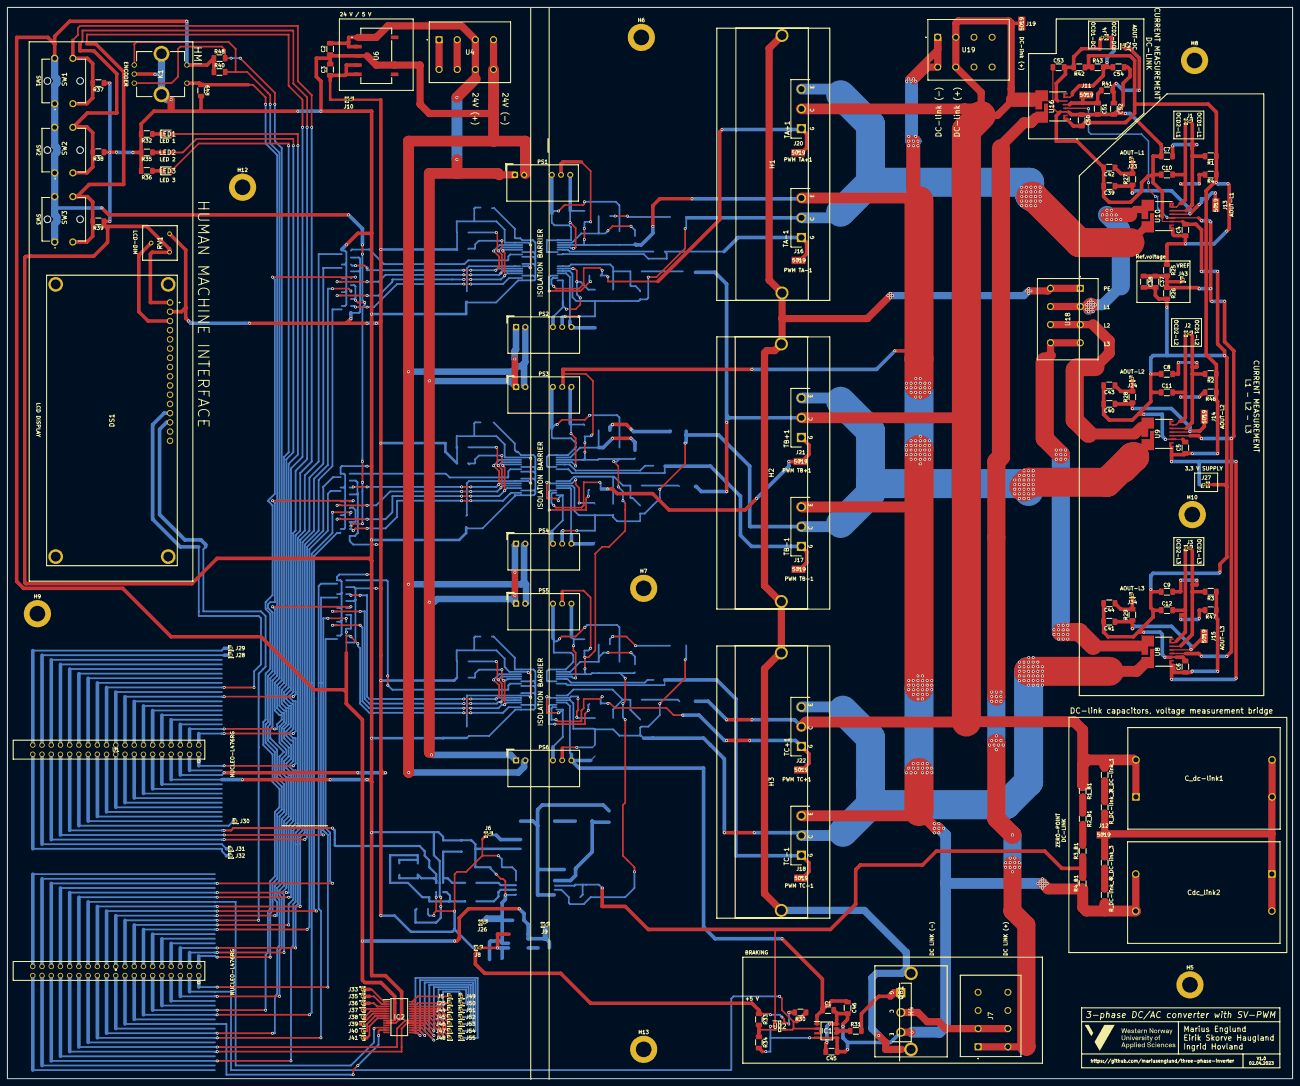
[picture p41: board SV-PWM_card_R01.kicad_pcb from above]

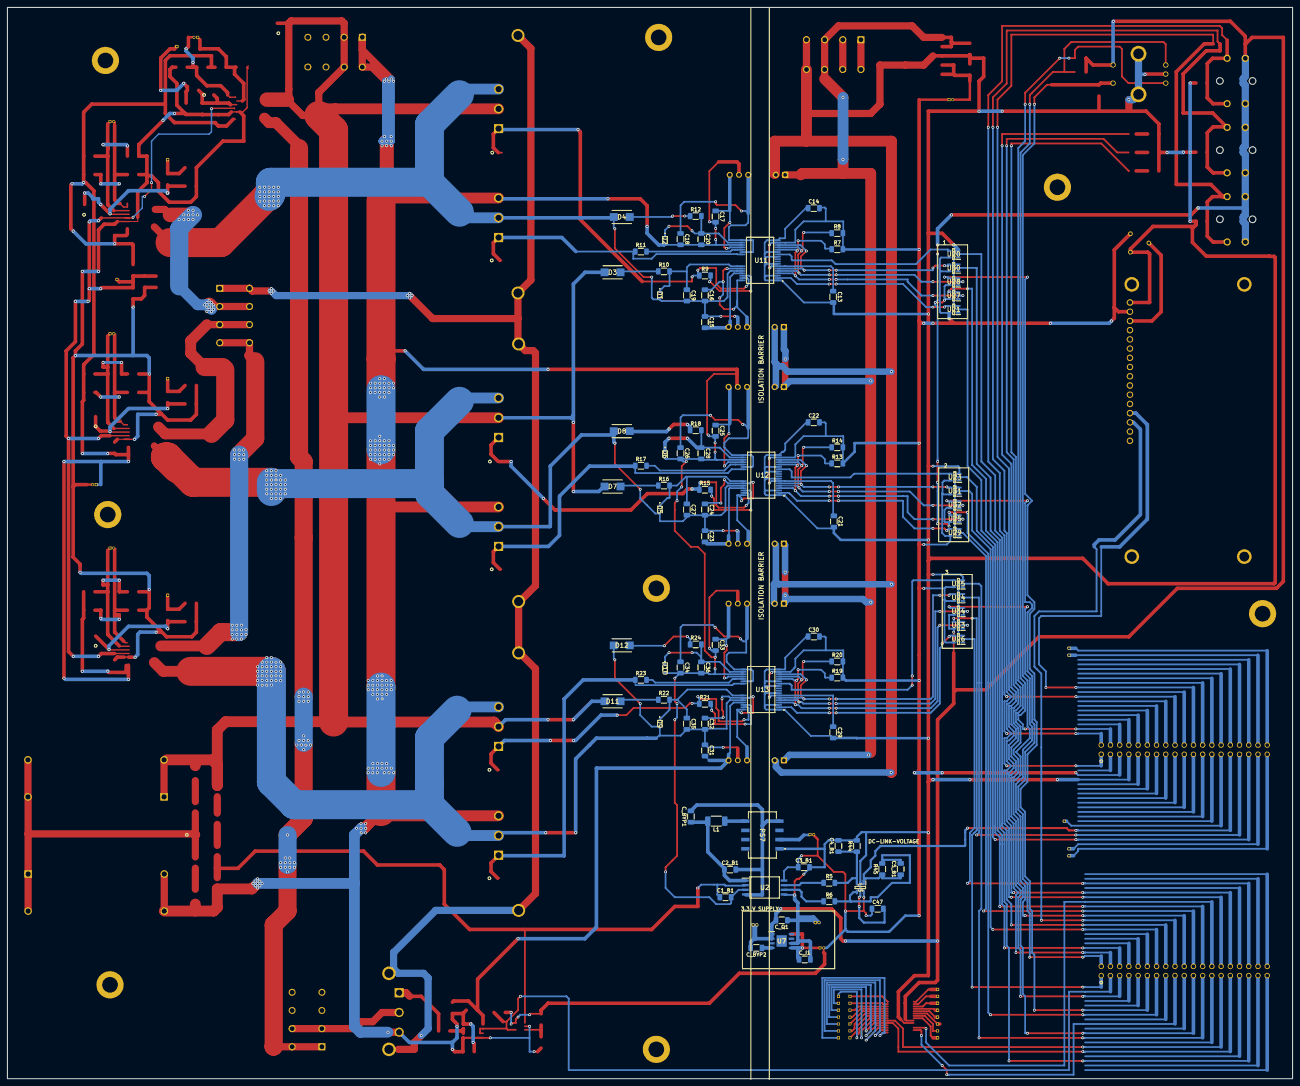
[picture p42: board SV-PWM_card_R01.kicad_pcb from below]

Board: 2 copper layers, 354.0 x 295.1 mm, 256 parts (91 on the bottom side), 153 nets.

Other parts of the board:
H5: MountingHole; MountingHole_4.3mm_M4_DIN965_Pad

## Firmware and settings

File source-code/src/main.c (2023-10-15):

/**
  **********************************************************************************
  * @file           : main.c
  * @brief          : This is the main entrypoint for the application.
  * @author         : Marius Englund, Eirik Skorve Haugland, Ingrid Hovland
  **********************************************************************************
  * 
  * The central entry point for the program code that has been implemented for the 
  * NUCLEO-L476RG development board, which is utilized in the inverter.
  *
  **********************************************************************************
  */


/* Includes ----------------------------------------------------------------------*/
#include <stdbool.h>
#include <math.h>
#include <stdio.h>

#include <stm32l4xx_ll_usart.h>
#include <stm32l4xx_ll_gpio.h>
#include <stm32l4xx_ll_cortex.h>
#include <stm32l4xx_ll_rcc.h>
#include <stm32l4xx_ll_bus.h>
#include <stm32l4xx_ll_tim.h>
#include <stm32l4xx_ll_utils.h>
#include <stm32l4xx_ll_pwr.h>
#include <stm32l4xx_ll_system.h>

#include "bsp_timer.h"


/* Define Valid Modulation Algorithms --------------------------------------------*/
// Defines valid modulation schemes for the inverter.
typedef enum {
  SPWM = 0,
  SVPWM
} scheme_t;


/* Define Rotor Direction --------------------------------------------------------*/
// Defines valid rotation directions for the rotor.
typedef enum {
  CW = 0,
  CCW
} direction_t;


/* Define Valid Operating States -------------------------------------------------*/
// Defines valid operating states for the inverter.
typedef enum {
  NOT_READY = 0,
  READY,
  RUNNING,
  FAULT
} state_t;


/* Define Compare Struct ---------------------------------------------------------*/
// Defines a struct of compare values for the timer.
typedef struct {
  uint32_t L1;
  uint32_t L2;
  uint32_t L3;
} compare_t;


/* Define Global Variables -------------------------------------------------------*/
// Defines globally accessible variables.
uint32_t sine_res_g           = 0;              // No. of Compare Values for Each Period (max 1024).
float sine_table[] = {0,0.0627905195293134,0.125333233564304,0.187381314585725,0.248689887164855,0.309016994374947,0.368124552684678,0.425779291565073,0.481753674101715,0.535826794978997,0.587785252292473,0.63742398974869,0.684547105928689,0.728968627421412,0.770513242775789,0.809016994374947,0.844327925502015,0.876306680043864,0.904827052466019,0.929776485888251,0.951056516295154,0.968583161128631,0.982287250728689,0.992114701314478,0.998026728428272,1,0.998026728428272,0.992114701314478,0.982287250728689,0.968583161128631,0.951056516295154,0.929776485888251,0.904827052466019,0.876306680043864,0.844327925502015,0.809016994374947,0.770513242775789,0.728968627421412,0.684547105928689,0.63742398974869,0.587785252292473,0.535826794978997,0.481753674101715,0.425779291565072,0.368124552684678,0.309016994374947,0.248689887164855,0.187381314585725,0.125333233564304,0.0627905195293133,0,-0.0627905195293133,-0.125333233564304,-0.187381314585725,-0.248689887164855,-0.309016994374947,-0.368124552684678,-0.425779291565072,-0.481753674101715,-0.535826794978997,-0.587785252292473,-0.63742398974869,-0.684547105928689,-0.728968627421412,-0.770513242775789,-0.809016994374947,-0.844327925502015,-0.876306680043863,-0.90482705246602,-0.929776485888251,-0.951056516295154,-0.968583161128631,-0.982287250728689,-0.992114701314478,-0.998026728428272,-1,-0.998026728428272,-0.992114701314478,-0.982287250728689,-0.968583161128631,-0.951056516295154,-0.929776485888251,-0.90482705246602,-0.876306680043863,-0.844327925502015,-0.809016994374947,-0.770513242775789,-0.728968627421412,-0.684547105928689,-0.63742398974869,-0.587785252292473,-0.535826794978996,-0.481753674101715,-0.425779291565072,-0.368124552684678,-0.309016994374947,-0.248689887164854,-0.187381314585725,-0.125333233564304,-0.0627905195293138,0};


float Ud_g                    = 0;              // DC-link Voltage [V]
float f1_g                    = 0;              // Modulation Frequency [Hz]
float fs_g                    = 0;              // Switching Frequency [Hz]
float ma_g                    = 0;              // Amplitude Modulation Index
float mf_g                    = 0;              // Frequency Modulation Index
// float time_samples_g[1024]    = {0};            // Time Samples [s]

scheme_t algorithm_g          = SVPWM;          // Modulation Scheme

direction_t direction_g       = CW;             // Rotor Rotation Direction

state_t operating_state_g     = NOT_READY;      // Inverter Operating State


/* Define UART I/O ---------------------------------------------------------------*/
// I/O declarations for the universal asynchronous receiver-transmitter.
#define UART2_PORT            GPIOA             // UART2 Port
#define UART2_TX_PIN          LL_GPIO_PIN_2     // UART2 Transmitter Pin
#define UART2_RX_PIN          LL_GPIO_PIN_3     // UART2 Receiver Pin


/* Define Gate Drivers I/O -------------------------------------------------------*/
// I/O declarations for the gate drivers.
/* Gate Driver 1 */
#define DRIVER1_RDY_PORT      GPIOB             // Gate Driver Leg A Ready Port
#define DRIVER1_RDY_PIN       LL_GPIO_PIN_9     // Gate Driver Leg A Ready Pin
#define DRIVER1_INHS_PORT     GPIOA             // Gate Driver Leg A High Side PWM Port
#define DRIVER1_INHS_PIN      LL_GPIO_PIN_8     // Gate Driver Leg A High Side PWM Pin
#define DRIVER1_INLS_PORT     GPIOA             // Gate Driver Leg A Low Side PWM Port
#define DRIVER1_INLS_PIN      LL_GPIO_PIN_7     // Gate Driver Leg A Low Side PWM Pin
#define DRIVER1_RST_PORT      GPIOC             // Gate Driver Leg A Reset Port
#define DRIVER1_RST_PIN       LL_GPIO_PIN_4     // Gate Driver Leg A Reset Pin
#define DRIVER1_FLT_PORT      GPIOA             // Gate Driver Leg A Fault Port
#define DRIVER1_FLT_PIN       LL_GPIO_PIN_12    // Gate Driver Leg A Fault Pin

/* Gate Driver 2 */
#define DRIVER2_RDY_PORT      GPIOA             // Gate Driver Leg B Ready Port
#define DRIVER2_RDY_PIN       LL_GPIO_PIN_11    // Gate Driver Leg B Ready Pin
#define DRIVER2_INHS_PORT     GPIOA             // Gate Driver Leg B High Side PWM Port
#define DRIVER2_INHS_PIN      LL_GPIO_PIN_9     // Gate Driver Leg B High Side PWM Pin
#define DRIVER2_INLS_PORT     GPIOB             // Gate Driver Leg B Low Side PWM Port
#define DRIVER2_INLS_PIN      LL_GPIO_PIN_0     // Gate Driver Leg B Low Side PWM Pin
#define DRIVER2_RST_PORT      GPIOA             // Gate Driver Leg B Reset Port
#define DRIVER2_RST_PIN       LL_GPIO_PIN_6     // Gate Driver Leg B Reset Pin
#define DRIVER2_FLT_PORT      GPIOC             // Gate Driver Leg B Fault Port
#define DRIVER2_FLT_PIN       LL_GPIO_PIN_9     // Gate Driver Leg B Fault Pin

/* Gate Driver 3 */
#define DRIVER3_RDY_PORT      GPIOC             // Gate Driver Leg C Ready Port
#define DRIVER3_RDY_PIN       LL_GPIO_PIN_8     // Gate Driver Leg C Ready Pin
#define DRIVER3_INHS_PORT     GPIOA             // Gate Driver Leg C High Side PWM Port
#define DRIVER3_INHS_PIN      LL_GPIO_PIN_10    // Gate Driver Leg C High Side PWM Pin
#define DRIVER3_INLS_PORT     GPIOB             // Gate Driver Leg C Low Side PWM Port
#define DRIVER3_INLS_PIN      LL_GPIO_PIN_1     // Gate Driver Leg C Low Side PWM Pin
#define DRIVER3_RST_PORT      GPIOA             // Gate Driver Leg C Reset Port
#define DRIVER3_RST_PIN       LL_GPIO_PIN_4     // Gate Driver Leg C Reset Pin
#define DRIVER3_FLT_PORT      GPIOC             // Gate Driver Leg C Fault Port
#define DRIVER3_FLT_PIN       LL_GPIO_PIN_7     // Gate Driver Leg C Fault Pin


/* Define HMI I/O ----------------------------------------------------------------*/
// I/O declarations for the human–machine interface.
/* Start Button */
#define HMI_SW1_PORT          GPIOA             // HMI Start Button Port
#define HMI_SW1_PIN           LL_GPIO_PIN_15    // HMI Start Button Pin

/* Stop Button */
#define HMI_SW2_PORT          GPIOC             // HMI Stop Button Port
#define HMI_SW2_PIN           LL_GPIO_PIN_10    // HMI Stop Button Pin

/* Green LED */
#define HMI_LED1_PORT         GPIOB             // HMI Green LED Port
#define HMI_LED1_PIN          LL_GPIO_PIN_4     // HMI Green LED Pin

/* Yellow LED */
#define HMI_LED2_PORT         GPIOB             // HMI Yellow LED Port
#define HMI_LED2_PIN          LL_GPIO_PIN_5     // HMI Yellow LED Pin

/* Red LED */
#define HMI_LED3_PORT         GPIOB             // HMI Red LED Port
#define HMI_LED3_PIN          LL_GPIO_PIN_8     // HMI Red LED Pin


/* Configure System Clock --------------------------------------------------------*/
// Configures the system core clock frequency equal to 80 MHz.
void configure_system_clock(void) {

  LL_FLASH_SetLatency(LL_FLASH_LATENCY_4);
  while(LL_FLASH_GetLatency()!= LL_FLASH_LATENCY_4){
  }
  LL_PWR_SetRegulVoltageScaling(LL_PWR_REGU_VOLTAGE_SCALE1);
  LL_RCC_HSI_Enable();

   /* Wait till HSI is Ready */
  while(LL_RCC_HSI_IsReady() != 1){
  }
  LL_RCC_HSI_SetCalibTrimming(16);
  LL_RCC_PLL_ConfigDomain_SYS(LL_RCC_PLLSOURCE_HSI, LL_RCC_PLLM_DIV_1, 10, LL_RCC_PLLR_DIV_2);
  LL_RCC_PLL_EnableDomain_SYS();
  LL_RCC_PLL_Enable();

   /* Wait till PLL is Ready */
  while(LL_RCC_PLL_IsReady() != 1){
  }
  LL_RCC_SetSysClkSource(LL_RCC_SYS_CLKSOURCE_PLL);

   /* Wait till System Clock is Ready */
  while(LL_RCC_GetSysClkSource() != LL_RCC_SYS_CLKSOURCE_STATUS_PLL){
  }
  LL_RCC_SetAHBPrescaler(LL_RCC_SYSCLK_DIV_1);
  LL_RCC_SetAPB1Prescaler(LL_RCC_APB1_DIV_1);
  LL_RCC_SetAPB2Prescaler(LL_RCC_APB2_DIV_1);

  LL_Init1msTick(80000000); // 80 MHz

  LL_SetSystemCoreClock(80000000); // 80 MHz
}


/* Initialize UART ---------------------------------------------------------------*/
// Initializes the universal asynchronous receiver-transmitter.
void initialize_UART(void) {

    LL_AHB2_GRP1_EnableClock(LL_AHB2_GRP1_PERIPH_GPIOA);
    LL_GPIO_SetPinMode(UART2_PORT, UART2_TX_PIN, LL_GPIO_MODE_ALTERNATE);
    LL_GPIO_SetPinMode(UART2_PORT, UART2_RX_PIN, LL_GPIO_MODE_ALTERNATE);
    LL_GPIO_SetAFPin_0_7(UART2_PORT, UART2_TX_PIN, LL_GPIO_AF_7);
    LL_GPIO_SetAFPin_0_7(UART2_PORT, UART2_RX_PIN, LL_GPIO_AF_7);

    LL_APB1_GRP1_EnableClock(LL_APB1_GRP1_PERIPH_USART2);

    LL_RCC_SetUSARTClockSource(LL_RCC_USART2_CLKSOURCE_PCLK1);

    LL_USART_SetOverSampling(USART2, LL_USART_OVERSAMPLING_8);

    LL_USART_SetBaudRate(USART2, SystemCoreClock, LL_USART_OVERSAMPLING_8, 9600);

    LL_USART_EnableDirectionRx(USART2);
    LL_USART_EnableDirectionTx(USART2);

    LL_USART_Enable(USART2);
}


/* Set SysTick Frequency ---------------------------------------------------------*/
// Sets the SysTick_Handler() frequency [Hz].
void set_SysTick_frequency(uint32_t freq) {
  
  if (SysTick_Config(SystemCoreClock/freq)) {
    while (1); // Stop program if configuration failed.
  }
}


/* Initialize TIM1 ---------------------------------------------------------------*/
// Initializes TIM1 for PWM generation on CH1, CH1N, CH2, CH2N, CH3 and CH3N.
void initialize_TIM1(void) {

  /* Enable Peripheral Clock */
  LL_APB2_GRP1_EnableClock(LL_APB2_GRP1_PERIPH_TIM1);

  /* General Settings */
  LL_TIM_SetCounterMode(TIM1, LL_TIM_COUNTERMODE_UP);
  LL_TIM_SetClockDivision(TIM1, LL_TIM_CLOCKDIVISION_DIV1);
  LL_TIM_SetRepetitionCounter(TIM1, 0);
  LL_TIM_EnableARRPreload(TIM1);
  LL_TIM_SetClockSource(TIM1, LL_TIM_CLOCKSOURCE_INTERNAL);

  /* CH1 Settings */
  LL_TIM_OC_EnablePreload(TIM1, LL_TIM_CHANNEL_CH1);
  LL_TIM_OC_SetMode(TIM1, LL_TIM_CHANNEL_CH1, LL_TIM_OCMODE_PWM1);
  LL_TIM_OC_SetPolarity(TIM1, LL_TIM_CHANNEL_CH1, LL_TIM_OCPOLARITY_HIGH);
  LL_TIM_OC_SetPolarity(TIM1, LL_TIM_CHANNEL_CH1N, LL_TIM_OCPOLARITY_HIGH);
  LL_TIM_OC_SetIdleState(TIM1, LL_TIM_CHANNEL_CH1, LL_TIM_OCIDLESTATE_LOW);
  LL_TIM_OC_SetIdleState(TIM1, LL_TIM_CHANNEL_CH1N, LL_TIM_OCIDLESTATE_LOW);
  LL_TIM_OC_EnableFast(TIM1, LL_TIM_CHANNEL_CH1);

  /* CH2 Settings */
  LL_TIM_OC_EnablePreload(TIM1, LL_TIM_CHANNEL_CH2);
  LL_TIM_OC_SetMode(TIM1, LL_TIM_CHANNEL_CH2, LL_TIM_OCMODE_PWM1);
  LL_TIM_OC_SetPolarity(TIM1, LL_TIM_CHANNEL_CH2, LL_TIM_OCPOLARITY_HIGH);
  LL_TIM_OC_SetPolarity(TIM1, LL_TIM_CHANNEL_CH2N, LL_TIM_OCPOLARITY_HIGH);
  LL_TIM_OC_SetIdleState(TIM1, LL_TIM_CHANNEL_CH2, LL_TIM_OCIDLESTATE_LOW);
  LL_TIM_OC_SetIdleState(TIM1, LL_TIM_CHANNEL_CH2N, LL_TIM_OCIDLESTATE_LOW);
  LL_TIM_OC_EnableFast(TIM1, LL_TIM_CHANNEL_CH2);

  /* CH3 Settings */
  LL_TIM_OC_EnablePreload(TIM1, LL_TIM_CHANNEL_CH3);
  LL_TIM_OC_SetMode(TIM1, LL_TIM_CHANNEL_CH3, LL_TIM_OCMODE_PWM1);
  LL_TIM_OC_SetPolarity(TIM1, LL_TIM_CHANNEL_CH3, LL_TIM_OCPOLARITY_HIGH);
  LL_TIM_OC_SetPolarity(TIM1, LL_TIM_CHANNEL_CH3N, LL_TIM_OCPOLARITY_HIGH);
  LL_TIM_OC_SetIdleState(TIM1, LL_TIM_CHANNEL_CH3, LL_TIM_OCIDLESTATE_LOW);
  LL_TIM_OC_SetIdleState(TIM1, LL_TIM_CHANNEL_CH3N, LL_TIM_OCIDLESTATE_LOW);
  LL_TIM_OC_EnableFast(TIM1, LL_TIM_CHANNEL_CH3);

  /* Other Settings */
  LL_TIM_SetOCRefClearInputSource(TIM1, LL_TIM_OCREF_CLR_INT_NC);
  LL_TIM_DisableExternalClock(TIM1);
  LL_TIM_ConfigETR(TIM1, LL_TIM_ETR_POLARITY_NONINVERTED, LL_TIM_ETR_PRESCALER_DIV1, LL_TIM_ETR_FILTER_FDIV1);
  LL_TIM_SetTriggerOutput(TIM1, LL_TIM_TRGO_RESET);
  LL_TIM_SetTriggerOutput2(TIM1, LL_TIM_TRGO2_RESET);
  LL_TIM_DisableMasterSlaveMode(TIM1);
  LL_TIM_OC_SetDeadTime(TIM1, 32);

  /* Enable PWM Outputs */
  LL_TIM_EnableAllOutputs(TIM1);
  LL_TIM_CC_EnableChannel(TIM1, LL_TIM_CHANNEL_CH1);
  LL_TIM_CC_EnableChannel(TIM1, LL_TIM_CHANNEL_CH1N); 
  LL_TIM_CC_EnableChannel(TIM1, LL_TIM_CHANNEL_CH2);
  LL_TIM_CC_EnableChannel(TIM1, LL_TIM_CHANNEL_CH2N);
  LL_TIM_CC_EnableChannel(TIM1, LL_TIM_CHANNEL_CH3); 
  LL_TIM_CC_EnableChannel(TIM1, LL_TIM_CHANNEL_CH3N);
}


/* Initialize TIM2 ---------------------------------------------------------------*/
// Initializes TIM2 for interrupt requests.
void initialize_TIM2(void) {

  /* Enable Peripheral Clock */
  LL_APB1_GRP1_EnableClock(LL_APB1_GRP1_PERIPH_TIM2);

  /* General Settings */
  LL_TIM_SetCounterMode(TIM2, LL_TIM_COUNTERMODE_UP);
  LL_TIM_SetClockDivision(TIM2, LL_TIM_CLOCKDIVISION_DIV1);
  LL_TIM_DisableARRPreload(TIM2);
  LL_TIM_SetClockSource(TIM2, LL_TIM_CLOCKSOURCE_INTERNAL);
  LL_TIM_SetTriggerOutput(TIM2, LL_TIM_TRGO_RESET);
  LL_TIM_DisableMasterSlaveMode(TIM2);
  LL_TIM_EnableIT_UPDATE(TIM2);

  /* IRQ Settings */
  NVIC_SetPriority(TIM2_IRQn, NVIC_EncodePriority(NVIC_GetPriorityGrouping(),0, 0));
  NVIC_EnableIRQ(TIM2_IRQn);
}


/* Enable GPIO Ports Clock -------------------------------------------------------*/
// Enables the GPIO ports clock.
void enable_gpio_ports_clock(void) {

  /* Enable GPIO Ports Clock */
  LL_AHB2_GRP1_EnableClock(LL_AHB2_GRP1_PERIPH_GPIOA);
  LL_AHB2_GRP1_EnableClock(LL_AHB2_GRP1_PERIPH_GPIOB);
  LL_AHB2_GRP1_EnableClock(LL_AHB2_GRP1_PERIPH_GPIOC);
}
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
int main(void) {

  /* Configure System Clock */
  configure_system_clock();

  /* Initialize UART */
  initialize_UART();

  /* Initialize Timer */
  initialize_TIM1();
  initialize_TIM2();

  /* Initialize GPIO */
  enable_gpio_ports_clock();
  initialize_gate_drivers();
  initialize_hmi();

  /* Define Inital Start Parameters */
  set_Ud(565.0);
  set_ma(1.0);
  set_modulation_frequency(50.0);
  set_switching_frequency(5000.0);
  set_rotor_direction(CW);
  set_modulation_algorithm(SPWM);
  set_sine_res(101);
  set_operating_state(READY);

  // start_modulation();


  // char buf[128];
  // snprintf(buf, sizeof(buf), "Avgitt spenning: %d V\nFrekvens: %d Hz", 400, 50);
  // print_str(buf);



  /* Endless Loop */
  while (true) {

    /* Check Operating State */
    state_t operating_state = get_operating_state();

    switch (operating_state) {
      case NOT_READY:
        set_green_led_state(false);
        set_yellow_led_state(false);
        set_red_led_state(false);
        break;

      case READY:
        set_green_led_state(false);
        set_yellow_led_state(true);
        set_red_led_state(false);
        break;

      case RUNNING:
        set_green_led_state(true);
        set_yellow_led_state(false);
        set_red_led_state(false);
        break;

      case FAULT:
        set_green_led_state(false);
        set_yellow_led_state(false);
        set_red_led_state(true);
        break;
      
      default:
        break;
    }

    /* Check Start Button */
    static bool SW1_last_state = false;
    bool SW1_state = LL_GPIO_IsInputPinSet(HMI_SW1_PORT, HMI_SW1_PIN);
    if(SW1_state != SW1_last_state) {
      if(SW1_state) { // The button went from off to on
        start_modulation();
        set_operating_state(RUNNING);
      }
      SW1_last_state = SW1_state;
    }

    /* Check Stop Button */
    static bool SW2_last_state = false;
    bool SW2_state = LL_GPIO_IsInputPinSet(HMI_SW2_PORT, HMI_SW2_PIN);
    if(SW2_state != SW2_last_state) {
      if(SW2_state) { // The button went from off to on
        stop_modulation();
        set_operating_state(READY);
      }
      SW2_last_state = SW2_state;
    }
  }
}

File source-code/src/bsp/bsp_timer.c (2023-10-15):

#include <stdint.h>
#include <stm32l4xx_ll_tim.h>


/* Set TIM1 Frequency ------------------------------------------------------------*/
// Sets the frequency of TIM1s clock and tick triggers.
void bsp_set_TIM1_frequency(uint32_t freq_clock, uint32_t freq_tick) {

    /* Set Timer Prescaler */
    uint32_t k_prescale = (uint32_t)(SystemCoreClock/freq_clock)-1;
    LL_TIM_SetPrescaler(TIM1, k_prescale);
    
    /* Set Timer Auto Reload */
    uint32_t k_reload = (uint32_t)(freq_clock/freq_tick)-1;
    LL_TIM_SetAutoReload(TIM1, k_reload);
}


/* Set TIM1 Compare --------------------------------------------------------------*/
// Sets the compare parameters for TIM1s CH1, CH2 and CH3.
void bsp_set_TIM1_compare(uint32_t comp_CH1, uint32_t comp_CH2, uint32_t comp_CH3) {
    
    /* Set Timer Compare */
    LL_TIM_OC_SetCompareCH1(TIM1, comp_CH1);
    LL_TIM_OC_SetCompareCH2(TIM1, comp_CH2);
    LL_TIM_OC_SetCompareCH3(TIM1, comp_CH3);
}


/* Set TIM2 Interrupt Frequency --------------------------------------------------*/
// Sets the frequency of TIM2s clock and tick triggers.
void bsp_set_TIM2_frequency(uint32_t freq_clock, uint32_t freq_tick) {

    /* Set Timer Prescaler */
    uint32_t k_prescale = (uint32_t)(SystemCoreClock/freq_clock)-1;
    LL_TIM_SetPrescaler(TIM2, k_prescale);
    
    /* Set Timer Auto Reload */
    uint32_t k_reload = (uint32_t)(freq_clock/freq_tick)-1;
    LL_TIM_SetAutoReload(TIM2, k_reload);
}

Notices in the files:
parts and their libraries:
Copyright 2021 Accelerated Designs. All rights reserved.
